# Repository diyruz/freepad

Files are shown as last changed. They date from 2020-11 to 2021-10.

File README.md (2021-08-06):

# Freepad

Freepad is an open-source Zigbee remote intended to be used to have a customizable keypad to control your smart home devices.  

## How to compile
Follow this article https://zigdevwiki.github.io/Begin/IAR_install/

## There are different hardware versions of the console.
More details on the links:
* [Freepad v1](https://github.com/diyruz/freepad/README_FREEPAD_v1.md)
* [Freepad v2](https://github.com/diyruz/freepad/README_FREEPAD_v2.md)
* [LeTV mod](https://github.com/diyruz/freepad/README_LETV.md)

## Features list:
1. Single/double/triple/quadruple/many_x/hold&release
2. Touchlink reset
3. ONOFF bind
4. Level control bind
5. Bindings configuration
6. Remote reset

## How to join:
1. Press and hold the *first* button for 3-10 seconds (depending on whether the device is connected to the network) until the LED on the device flashes.
2. Wait, if the connection is successful, the device will blink 5 times.
3. If the connection fails, the device will blink 3 times.

***Find button mapping at project page***

### Support
The keypad is supported in:
* zigbee2mqtt via int & ext converter
* ioBroker
* SLS Gateway

## Settings
In zigbee2mqtt you could change the setting at Exposes tab.
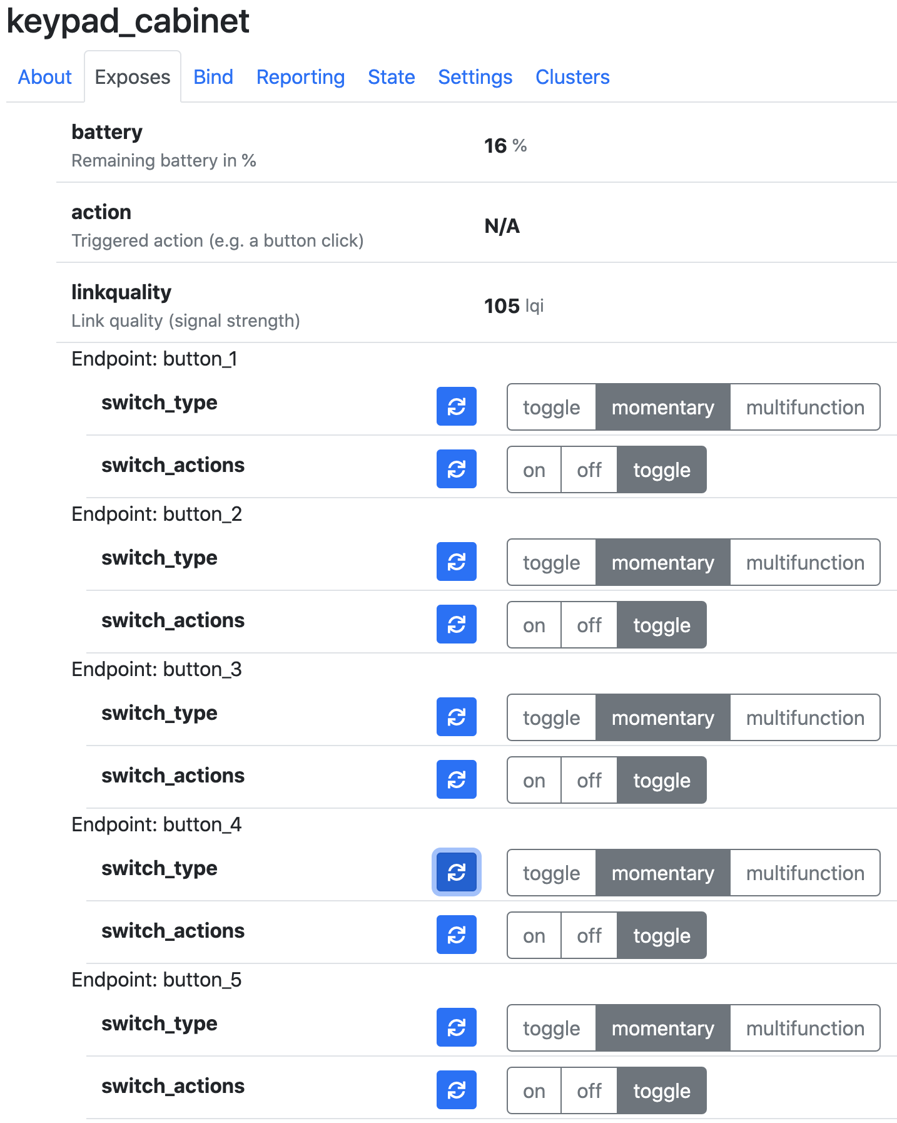
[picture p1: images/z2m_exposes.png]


### Work modes
By default remote works as a custom switch, with multiple clicks, but this behaviour has its drawback.
To detect multiple clicks, the remote sends commands with a 300ms delay.
You can change this behaviour by the cost of double/triple/etc clicks.

To do that you need to change

`ZCL_CLUSTER_ID_GEN_ON_OFF_SWITCH_CONFIG` cluster `ATTRID_ON_OFF_SWITCH_TYPE` attribute

Values are:

`ON_OFF_SWITCH_TYPE_MOMENTARY` (0) -> no delay, but no multiple clicks, only single

```bash
mosquitto_pub -t "zigbee2mqtt/FN/BUTTON_NUM/set/switch_type" -m '0'
```

`ON_OFF_SWITCH_TYPE_MULTIFUNCTION` (2) -> 300ms delay, full set of clicks

```bash
mosquitto_pub -t "zigbee2mqtt/FN/BUTTON_NUM/set/switch_type" -m '2'
```

### ONOFF cluster binding
By default command is TOGGLE, but you can change this behaviour.

Change `ZCL_CLUSTER_ID_GEN_ON_OFF_SWITCH_CONFIG` clusters attribute `ATTRID_ON_OFF_SWITCH_ACTIONS`

`ON_OFF_SWITCH_ACTIONS_ON`

```bash
mosquitto_pub -t "zigbee2mqtt/FN/BUTTON_NUM/set/switch_actions" -m '0'
```

`ON_OFF_SWITCH_ACTIONS_OFF`

```bash
mosquitto_pub -t "zigbee2mqtt/FN/BUTTON_NUM/set/switch_actions" -m '1'
```

`ON_OFF_SWITCH_ACTIONS_TOGGLE` (default value)

```bash
mosquitto_pub -t "zigbee2mqtt/FN/BUTTON_NUM/set/switch_actions" -m '2'
```

### Video
[@Vlad_Kolobov](http://t.me/@MoNo320) recorded a video showing the speed in two modes
video_speed_compare (https://www.youtube.com/watch?v=XvhNs9Tn12M)

### Acronyms in firmware file names

TL - touchlink

PM3 - Power Mode 3 (External Interrupts): 0.4 μA

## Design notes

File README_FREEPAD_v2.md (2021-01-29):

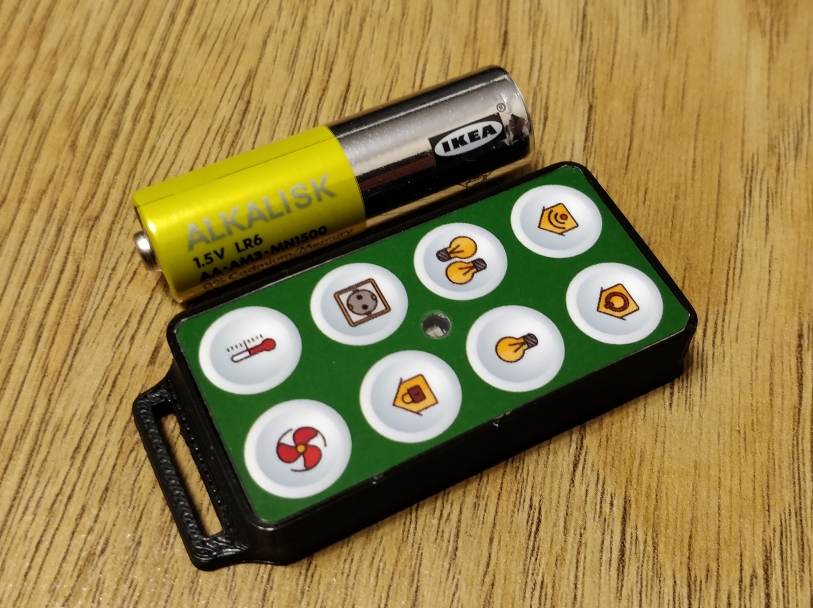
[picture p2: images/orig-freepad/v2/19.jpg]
  

The first version of the Zigbee remote control is good, but this option is not suitable when mobility is needed. For this reason, a second version appeared, in which Jager tried to make a more compact version.

Since 20 buttons are not always and not always needed, Jager had to come up with a board design that allows you to assemble 3 versions of remotes, for 20, 12, and 8 buttons. The following is a process with pictures and short explanations.

The circuit is almost identical to the first version
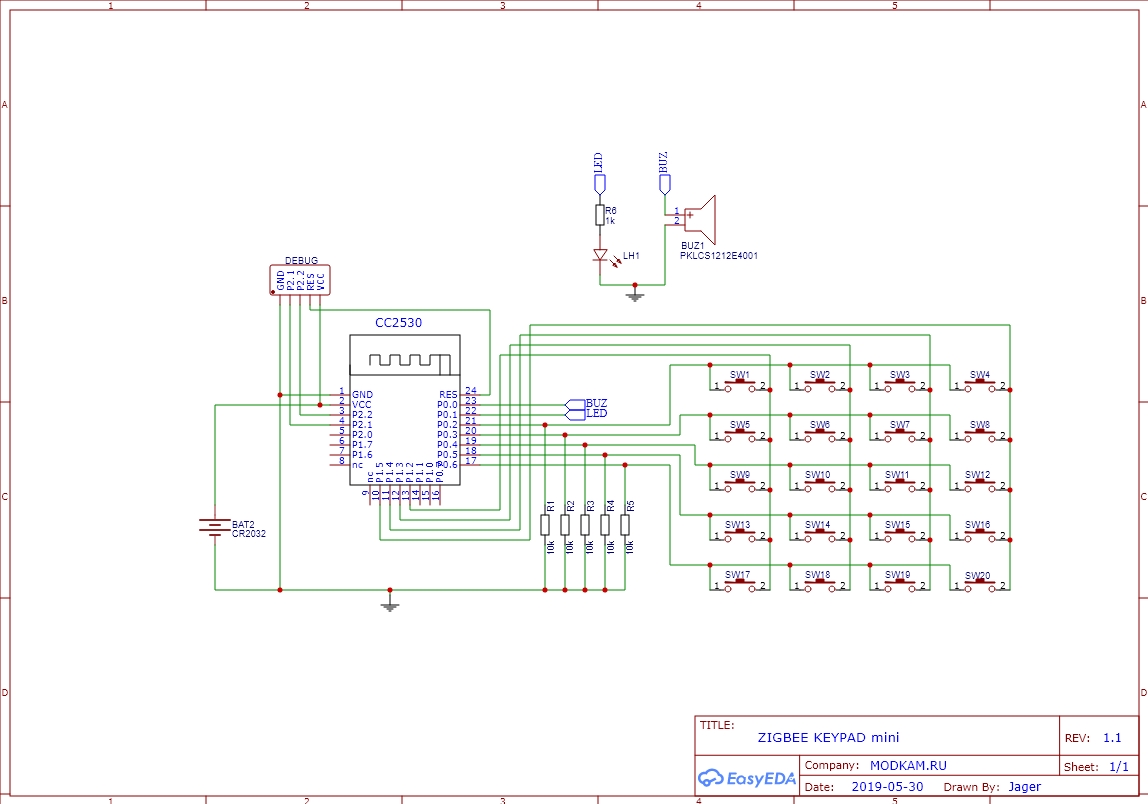
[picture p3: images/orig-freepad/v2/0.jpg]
  

using the Zigbee module from EBYTE E18-MS1-PCB
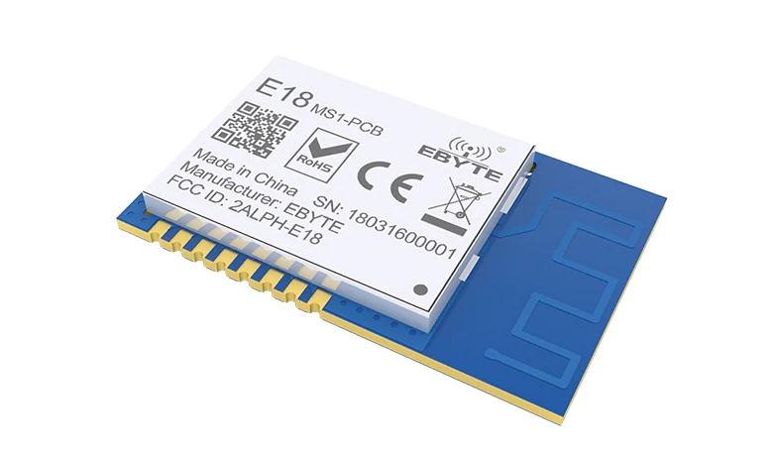
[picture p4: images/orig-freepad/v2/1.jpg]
  

compact buttons 3x4x2 mm
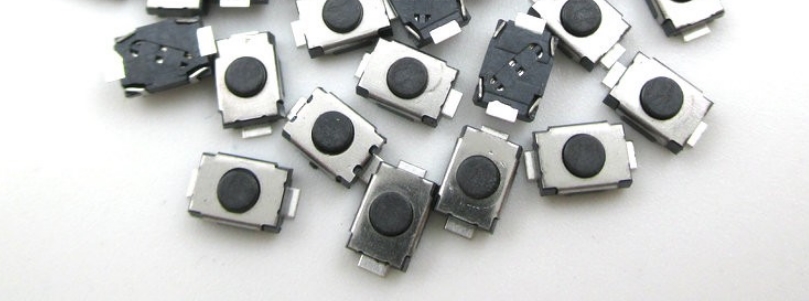
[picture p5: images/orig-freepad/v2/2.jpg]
  

The board is wired in DiTrace  
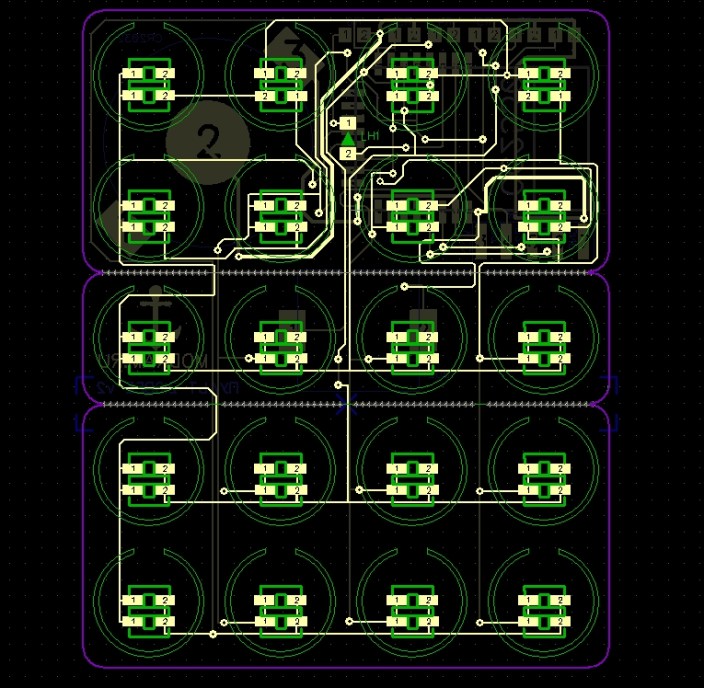
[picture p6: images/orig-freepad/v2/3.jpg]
  
Note that the contact pads for the buttons are not designed for 4 pin buttons, as it might seem, these are options for a different offset from the center, due to the design of the case.

Perforation is clearly visible on the renders, in these places unnecessary buttons are “broken off”. The very idea of separating the excess is certainly not new, but those restrictions are imposed on the flight of thought. manufacturer's conditions. Instead of cutouts, Jager had to make holes with a diameter of 0.3 mm.
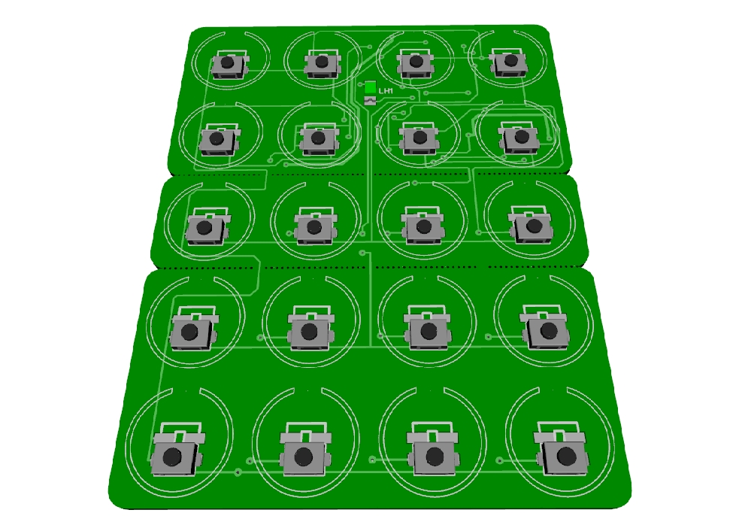
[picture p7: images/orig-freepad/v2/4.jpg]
  

Boards ordered in JLCPCB
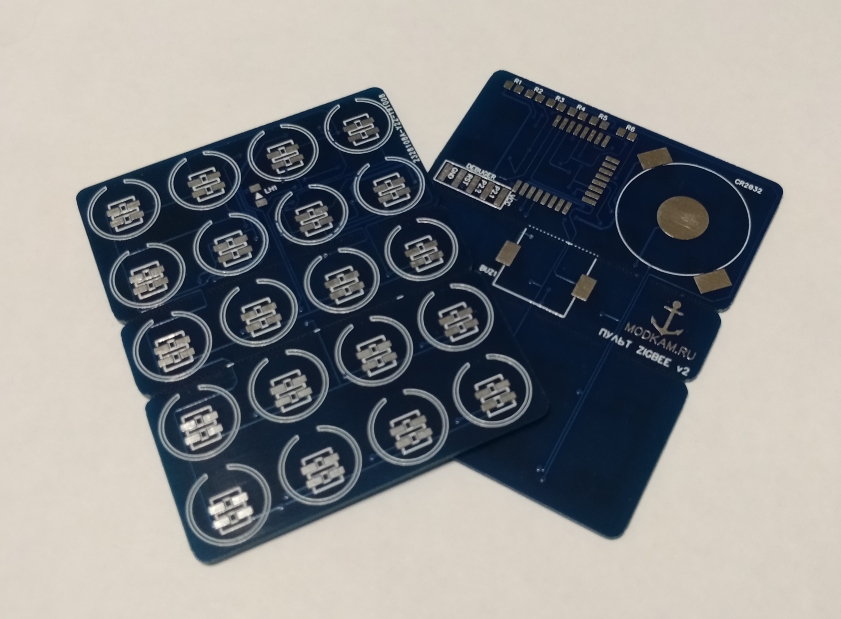
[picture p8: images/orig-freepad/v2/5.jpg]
  

Minimum soldering  
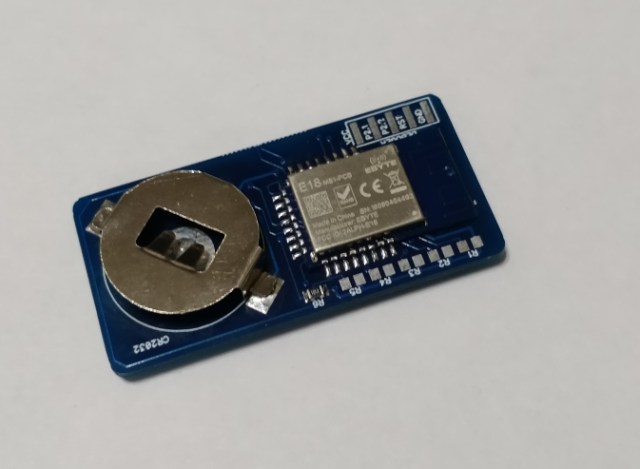
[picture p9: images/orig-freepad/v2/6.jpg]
  

Made a variant of the case for eight buttons in the form of a keychain. 
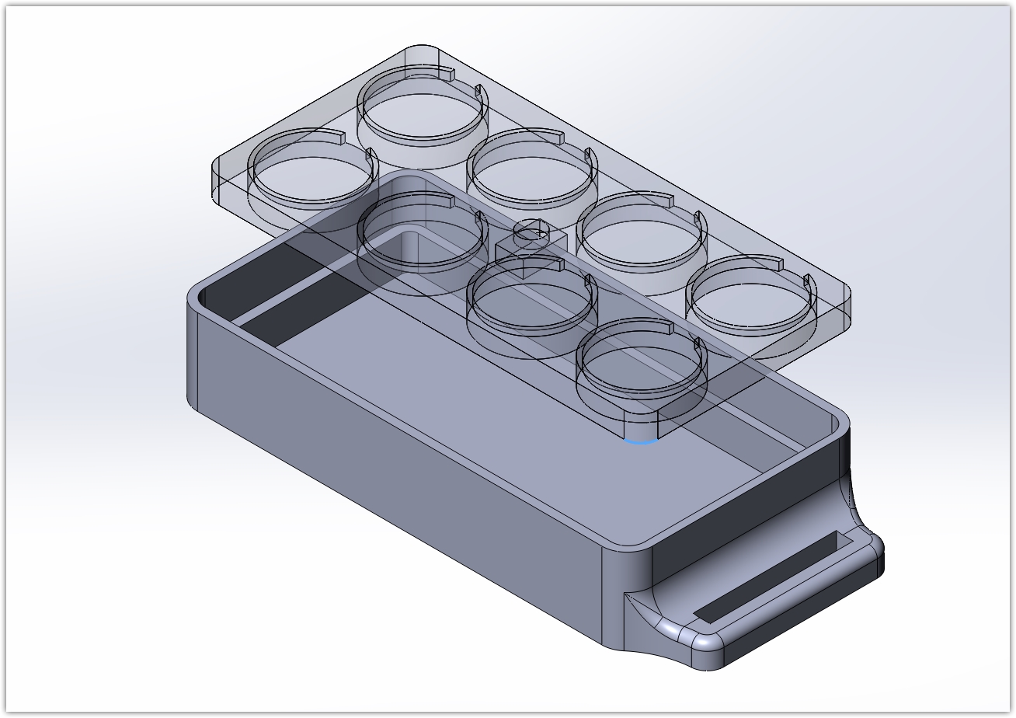
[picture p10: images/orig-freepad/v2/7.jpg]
  
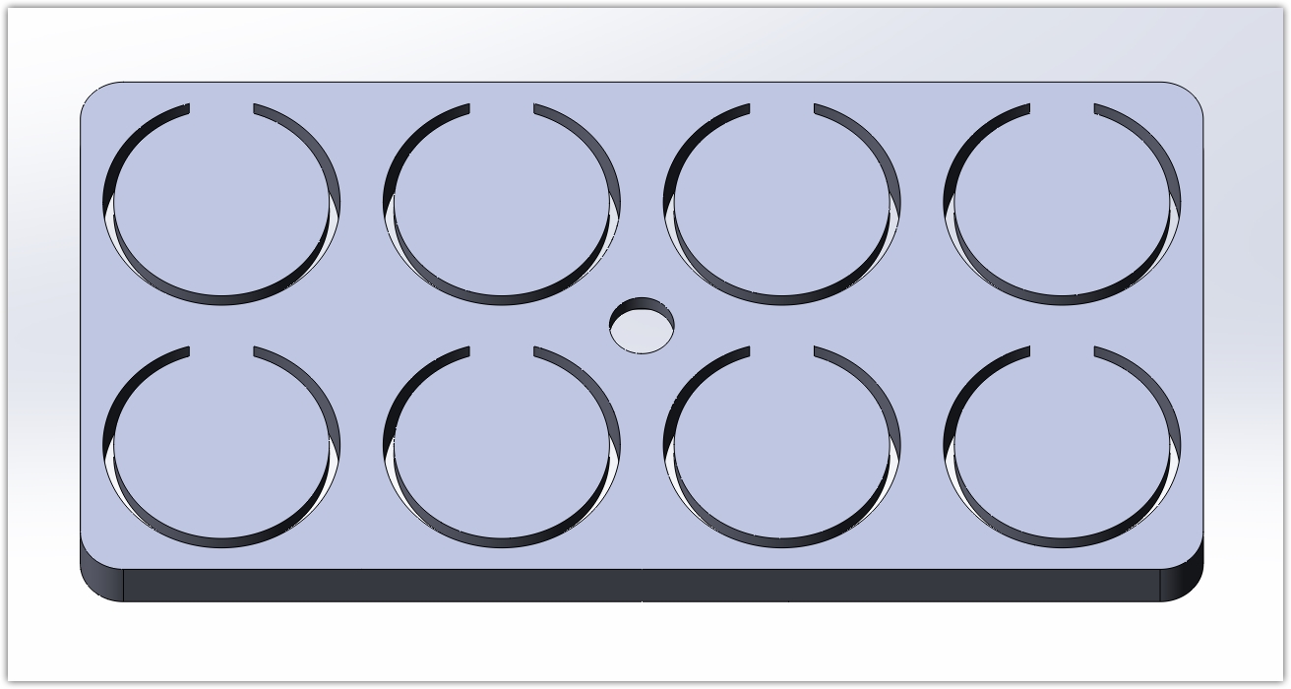
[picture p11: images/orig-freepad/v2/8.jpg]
  
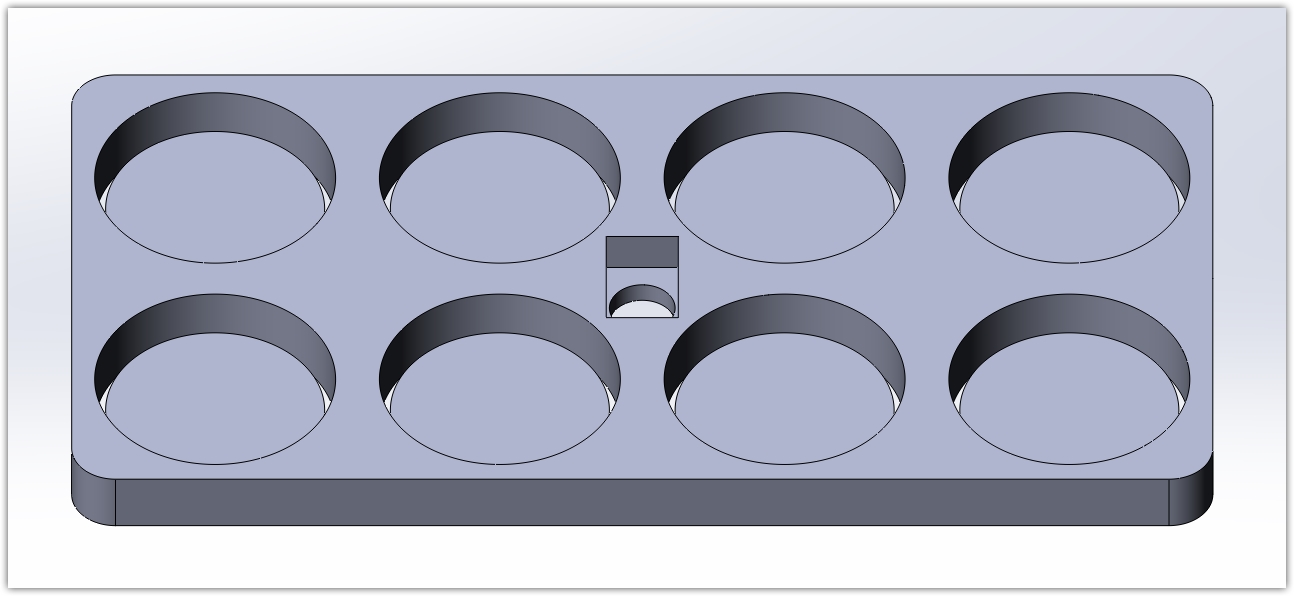
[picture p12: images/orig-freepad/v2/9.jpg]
  
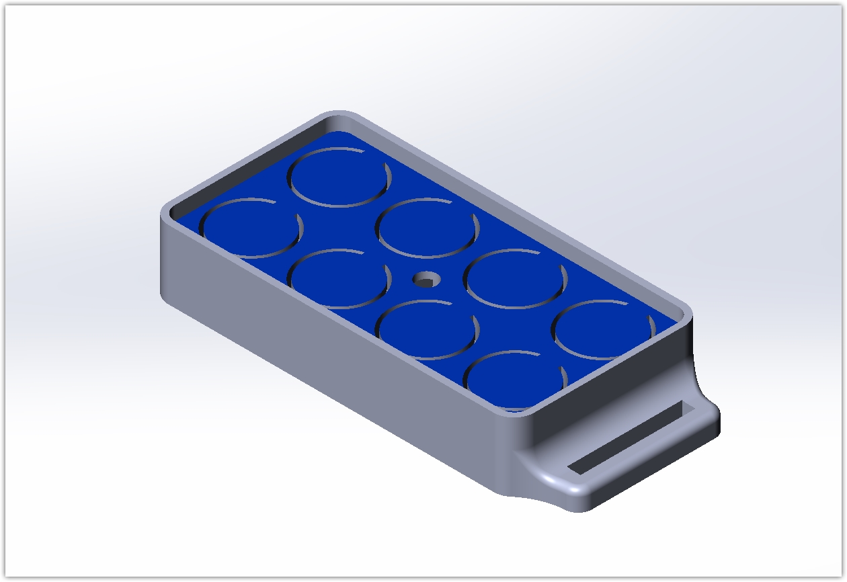
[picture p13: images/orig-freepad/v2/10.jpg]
  

The general idea is this, the insert on top of the board allows you to distribute the force over a larger area
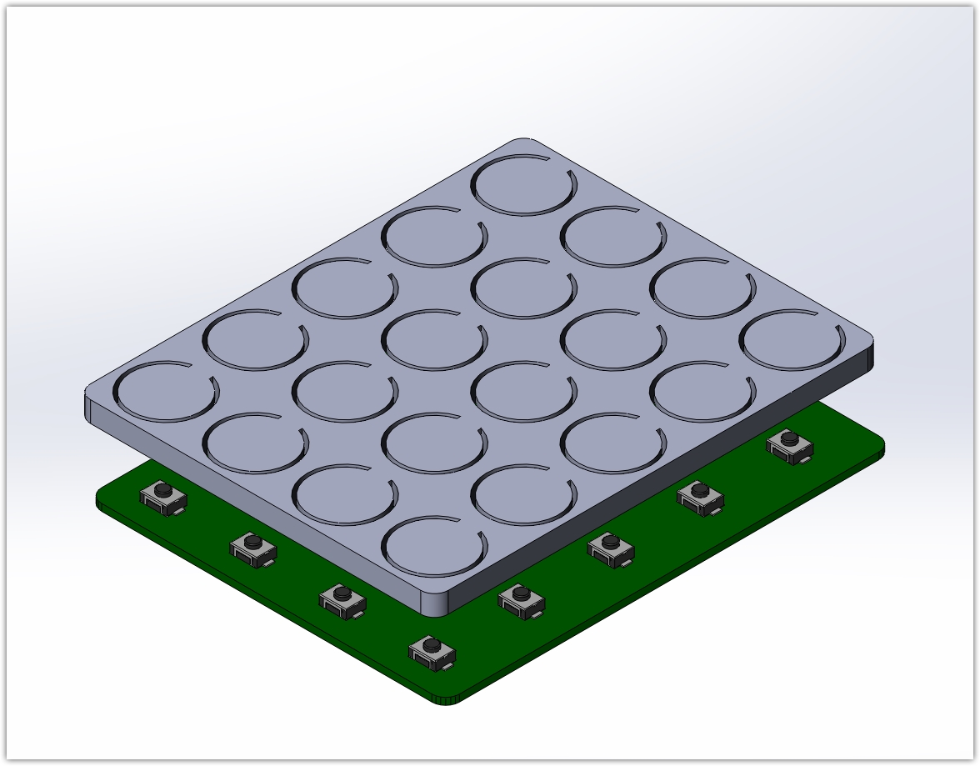
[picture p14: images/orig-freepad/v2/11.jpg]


Printed on 3d printer  
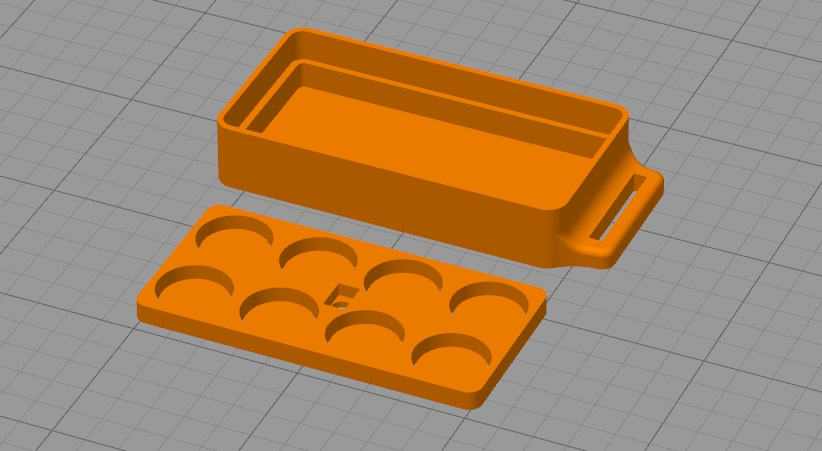
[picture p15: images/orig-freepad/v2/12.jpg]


First tried on  
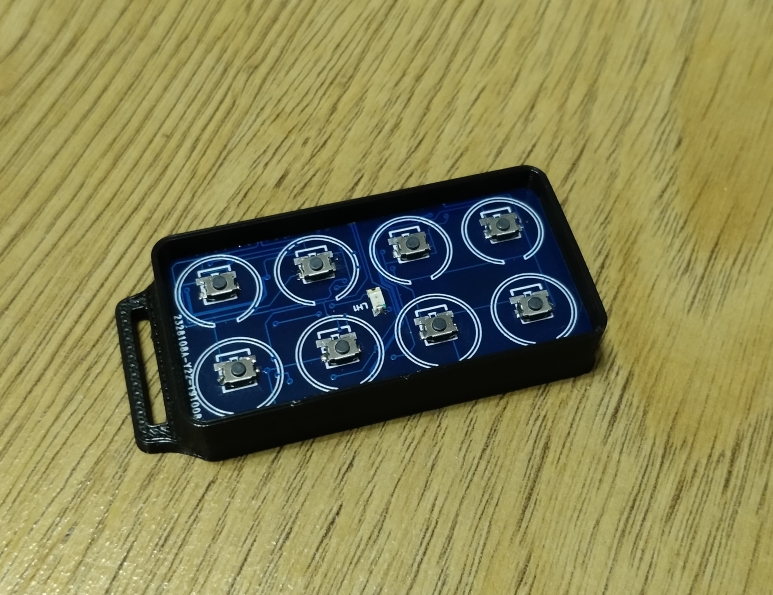
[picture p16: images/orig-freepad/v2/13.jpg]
  

The keyboard
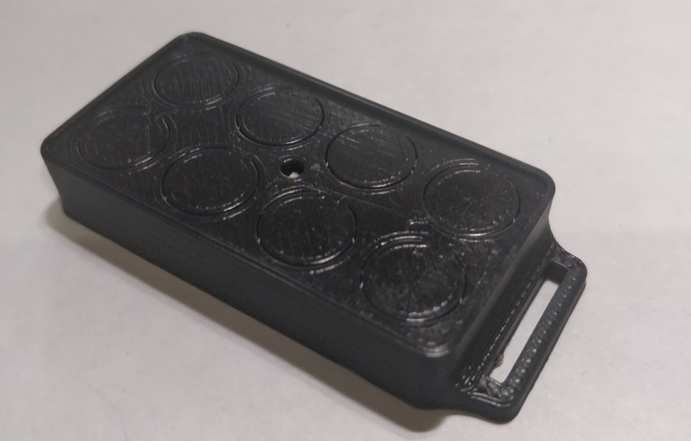
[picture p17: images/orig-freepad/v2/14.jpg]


Different colors  
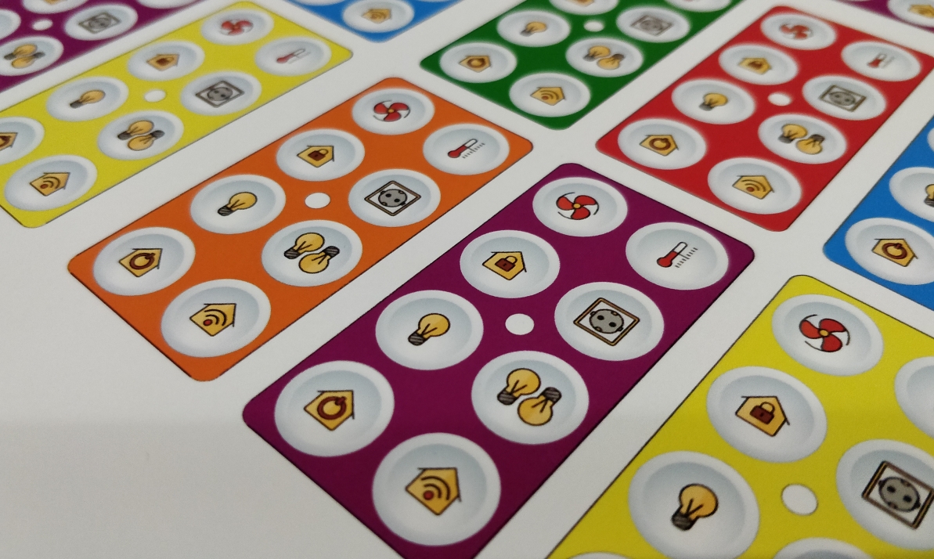
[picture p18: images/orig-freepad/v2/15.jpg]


Lamination will protect the paper keyboard

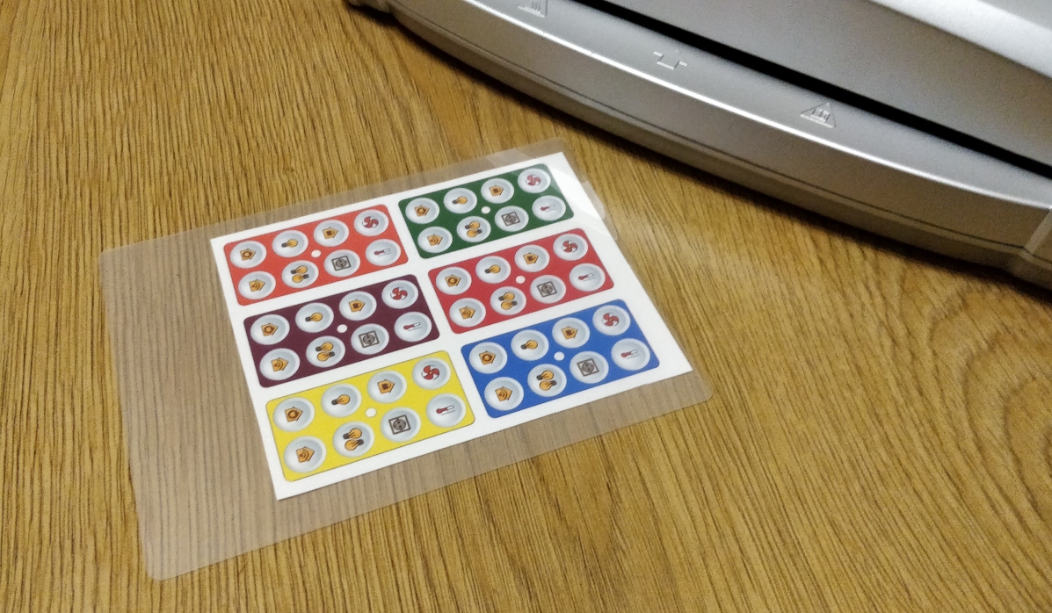
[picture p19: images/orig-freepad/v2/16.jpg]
  

Remains only to cut and try  
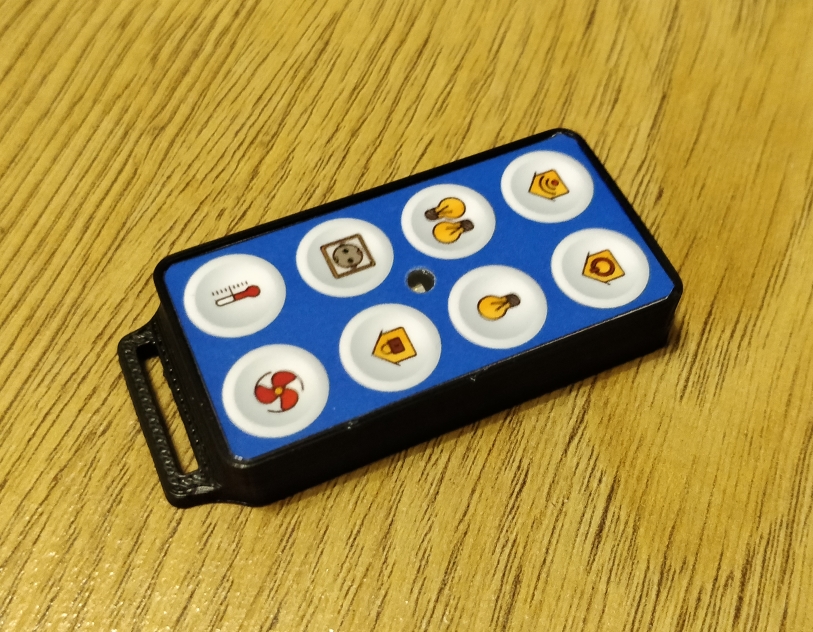
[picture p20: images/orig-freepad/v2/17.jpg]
  
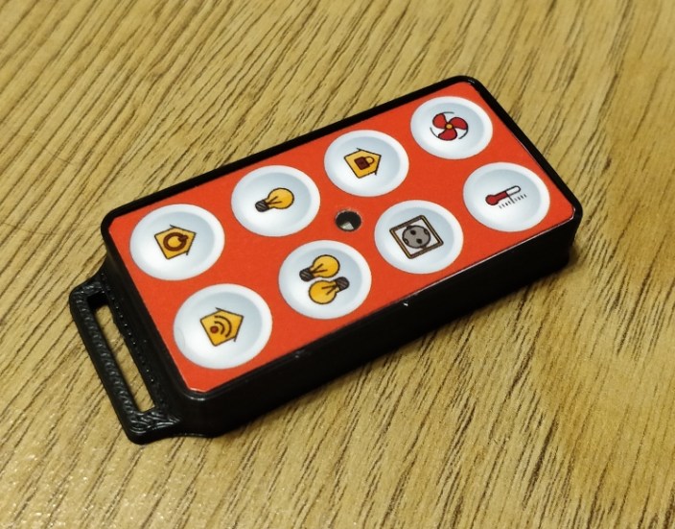
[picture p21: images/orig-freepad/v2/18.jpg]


In scale  
  
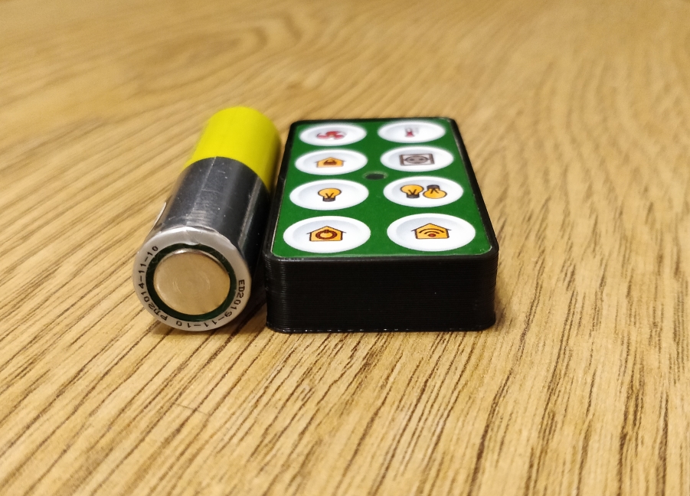
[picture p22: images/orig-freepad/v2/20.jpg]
  

Compared to first version  
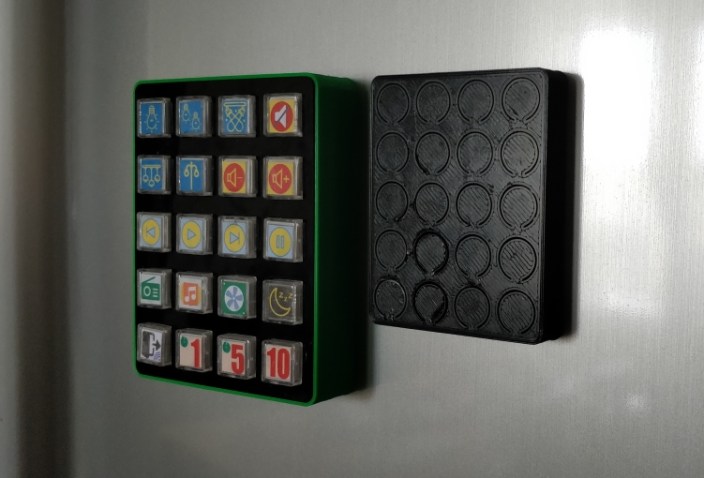
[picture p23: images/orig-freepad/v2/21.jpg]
  

From the software point of view, the consoles are identical.

@anonymass has written a open source firmware. The firmware has a lot of  options, binding, multi-click, etc. High stability and speed.

@nick7zmail repeated the construction, making the original keyboard
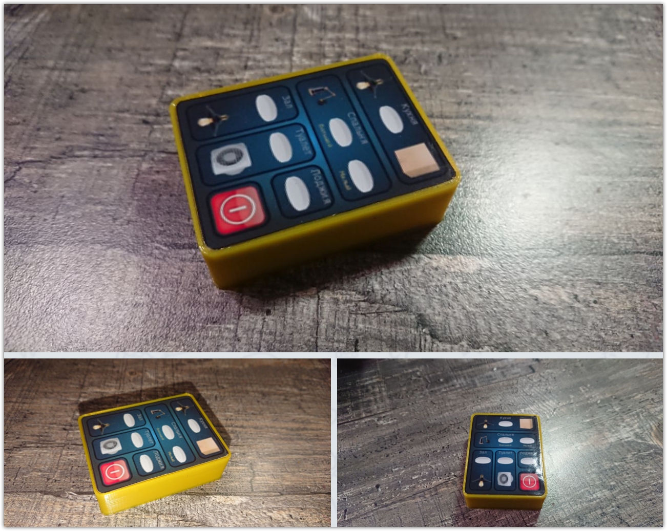
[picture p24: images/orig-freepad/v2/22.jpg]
  

but he did not stop there and made various housing options, for 8, 12, and 20 buttons.
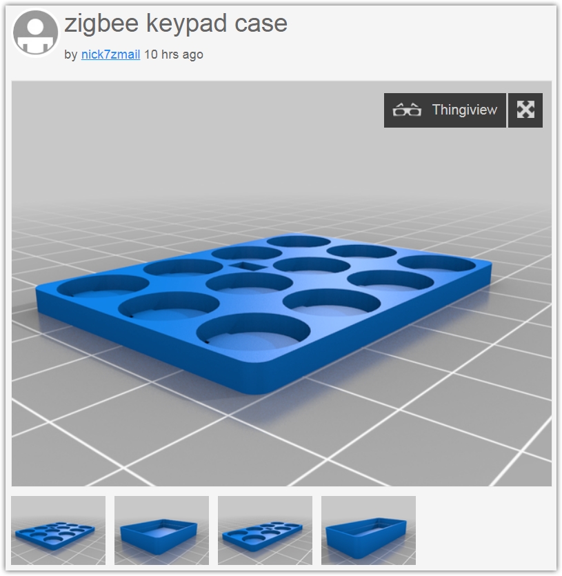
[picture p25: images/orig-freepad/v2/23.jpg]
  

@Madjestik58 designed and manufactured his version of the 4 button remote all necessary files for manufacturing are included.
  

Another version of the case for the keypad from obihoernchen
  

### What's button mapping?


### Files to reproduce
* [Gerbers and STL for 8 button](https://github.com/diyruz/freepad/hardware/v2) by [Jager](https://t.me/Jager_f)  
* [EasyEDA and STL for 4 button](https://github.com/diyruz/freepad/hardware/4_buttons) by [@Madjestik58](https://t.me/Madjestik58)  
* [Housing for 8, 12 and 20 buttons](https://www.thingiverse.com/thing:4161582) by [@nick7zmail](https://connect.smartliving.ru/profile/225)  
* [Housing for 20 buttons](https://www.thingiverse.com/thing:4668986) by [obihoernchen](https://www.thingiverse.com/obihoernchen)  
* [Firmware](https://github.com/diyruz/freepad/releases) by [@anonymass](https://t.me/anonymass)  
choose firmware hex file __without LeTV__ suffix

[Original post by Jager](https://modkam.ru/?p=1264)

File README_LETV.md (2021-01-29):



Some time ago, digging TaoBao, Jager has found an interesting miniature ZigBee remote control keypad with eight buttons.
As this device is powered by a CC2530 chip, an idea appeared in Jager's head to flash it with a great [freepad](https://github.com/diyruz/freepad/) firmware, which was used in Jager's previous remote controls.

UPD: This keypad has appeared on [AliExpress](https://aliexpress.ru/item/1005001962088229.html?&sku_id=12000018238549831)

Keypad has 8 buttons, two-colored led, and is powered by CR2032 lithium cell.




It is quite easy to disassemble this device. The case is held by plastic latches, and two screws hid beneath the white ring.



A totally disassembled keypad looks like this:





There are membrane buttons, held by a scotch duct-tape on the PCB.
The scotch-tape hides firmware flashing pads, so you need to remove it or cut a window to have access.



As you can see, contacts are located in a pretty chaotic order. I don't wish to solder wires and that's why I decided to make a flashing adapter.







The only thing you need to do is to upload the modified by [@xyzroe](https://t.me/xyzroe) version of freepad [firmware](https://github.com/diyruz/freepad/) with any
situated flashing [method](https://zigbee.wiki/books/%D0%BF%D1%80%D0%BE%D1%88%D0%B8%D0%B2%D0%BA%D0%B8/page/%D0%BF%D1%80%D0%BE%D1%88%D0%B8%D0%B2%D0%BA%D0%B0-cc2531cc2530).
Zigbee2mqtt converter file is included in the package archive.

Here is how the device attached to the [SLS Gateway](https://slsys.github.io/Gateway/README_rus.html) looks like:




### What's button mapping?


### Links
 - [DXF-file](https://github.com/diyruz/freepad/hardware/letv) by [Jager](https://t.me/Jager_f)  
   for DIY flashing adapter.

 - [Freepad firmware releases](https://github.com/diyruz/freepad/releases/latest)  
   choose firmware hex file with __LeTV__ suffix.  

 - [Flash instruction (in Russian)](https://zigbee.wiki/books/%D0%BF%D1%80%D0%BE%D1%88%D0%B8%D0%B2%D0%BA%D0%B8/page/%D0%BF%D1%80%D0%BE%D1%88%D0%B8%D0%B2%D0%BA%D0%B0-cc2531cc2530)  
   In Russian for now, but links and pictures are not less useful.

[Original post by Jager](https://modkam.ru/?p=1791)

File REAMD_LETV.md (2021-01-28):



Some time ago, digging TaoBao, I've found an interesting miniature ZigBee remote control keypad with eight buttons.
As this device is powered by a CC2530 chip, an idea appeared in my head to flash it with a great [freepad](https://github.com/diyruz/freepad/) firmware, which was used in my previous remote controls.

UPD: This keypad has appeared on [Aliexpress](https://aliexpress.ru/item/1005001962088229.html?&sku_id=12000018238549831)

Keypad has 8 buttons, two-colored led, and is powered by CR2032 lithium cell.




It is quite easy to disassemble this device. The case is held by plastic latches, and two screws hid beneath the white ring.



A totally disassembled keypad looks like this:





There are membrane buttons, held by a scotch duct-tape on the PCB.
The scotch-tape hides firmware flashing pads, so you need to remove it or cut a window to have access.



As you can see, contacts are located in a pretty chaotic order. I don't wish to solder wires and that's why I decided to make a flashing adapter.







The only thing you need to do is to upload the modified by [@xyzroe](https://t.me/xyzroe) version of freepad [firmware](https://github.com/diyruz/freepad/) with any 
situated flashing [method](https://zigbee.wiki/books/%D0%BF%D1%80%D0%BE%D1%88%D0%B8%D0%B2%D0%BA%D0%B8/page/%D0%BF%D1%80%D0%BE%D1%88%D0%B8%D0%B2%D0%BA%D0%B0-cc2531cc2530).
Zigbee2mqtt converter file is included in the package archive.

Here is how the device attached to the [SLS Gateway](https://slsys.github.io/Gateway/README_rus.html) looks like:




[Original post by Jager](https://modkam.ru/?p=1791)

### Links
 - [DXF-file](https://www.dropbox.com/s/y3p7kqxyiqmid25/LeTV_pogopin.dxf?dl=0)  
   for DIY flashing adapter.

 - [Freepad firmware releases](https://github.com/diyruz/freepad/releases/latest)  
   choose firmware hex file with __LeTV__ suffix.  

 - [Flash instruction (in Russian)](https://zigbee.wiki/books/%D0%BF%D1%80%D0%BE%D1%88%D0%B8%D0%B2%D0%BA%D0%B8/page/%D0%BF%D1%80%D0%BE%D1%88%D0%B8%D0%B2%D0%BA%D0%B0-cc2531cc2530)  
   In Russian for now, but links and pictures are not less useful.

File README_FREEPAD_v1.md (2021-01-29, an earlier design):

  

This is a kind of universal remote control, which displays the most frequently used functions in a particular room. This can be lighting control, multimedia equipment, various UD scenarios, etc.

This remote control will live in the kitchen, the icons show that it will be possible to control the light, hood, music, set the timer.

The device is based on a module from EBYTE E18-MS1-PCB or E18-MS1PA1-PCB if an increased communication range is required.
  
The advantages of this module are cheapness and ultra-low consumption, 0.4 μA in deep sleep mode.

The scheme uses a matrix of 20 buttons. The remote control is powered by one CR2032 element if a 2.5mW module is used, and from two elements via an LDO when using a 100mW module. There is also a LED and a buzzer on the diagram to indicate both the actual operation of the buttons and the display of service modes.  
  

The dimensions of the device are determined by buttons 12x12x7.3 mm with transparent covers, I must say on AliExpress, their choice is very limited and this is practically the only option. There is a version with contacts for surface mounting. , but you can also use such as in the picture, it is enough to "bite off" the legs flush with the body.  
  

The board was spread in DipTrace


Virtual result
  
  
Satisfied with the result, Jager place an order for the boards.

While the boards are being manufactured, Jager engaged in the case,
  
  

Then print on a 3D printer. For fastening to a metal surface, magnets 9 x 1.5 mm are provided, with an effort they snap into place. Fastening the board with M3x5 screws.
  

The upper part can also be printed, but it is much more aesthetically pleasing to cut out with a laser from plexiglass. Light transmittance 2%, enough to see the glow of the LED and hide the insides, 3mm thick.  Held in place by friction.  
  

Printed pictograms for buttons  
  

The boards are ready  
  

a little soldering  
  

and can be assembled for size estimation,
  
  

in comparison with the IKEA TRÅDFRI remote control
  

element AA
  

Variant of fastening to a metal surface  


The original firmware was written by Vladislav @DJONvl, support in the ioBroker driver was provided by Kirov Ilya @goofyk, for which special thanks to them.  
  

Consumption corresponds to the one declared by the manufacturer, which will allow the remote control to work from one CR2032 element from 1 to 2 years.  
  

The firmware implements both light and sound indications of pressing. There is a network presence control (if the device is out of the network, pressing the buttons is not confirmed by light and sound). Work on the functionality of the firmware continues, possibly binding, and other options will appear.

@anonymass has written a new open-source firmware. The firmware added a lot of new options, binding, multi-click, etc. Significantly improved stability and speed.

@Madjestik58 made his version of the case using other buttons, 12x12 5mm high. It turned out great!  

  

### What's button mapping?
 

### Files to reproduce
* [Gerbers, STL, DXF](https://github.com/diyruz/freepad/hardware/v2) by [Jager](https://t.me/Jager_f)  

* [Another housing](https://www.thingiverse.com/thing:4256330) by [@Madjestik58](https://t.me/Madjestik58)  

* [NEW firmware](https://github.com/diyruz/freepad/releases) by [@anonymass](https://t.me/anonymass)  
choose firmware hex file  __without LeTV__ suffix  

* [OLD original firmware hex](https://github.com/diyruz/freepad/hardware/v1/maxPW_key17setup_DIYRuZ_KEYPAD20.hex) by @DJONvl

[Original post by Jager](https://modkam.ru/?p=1114)

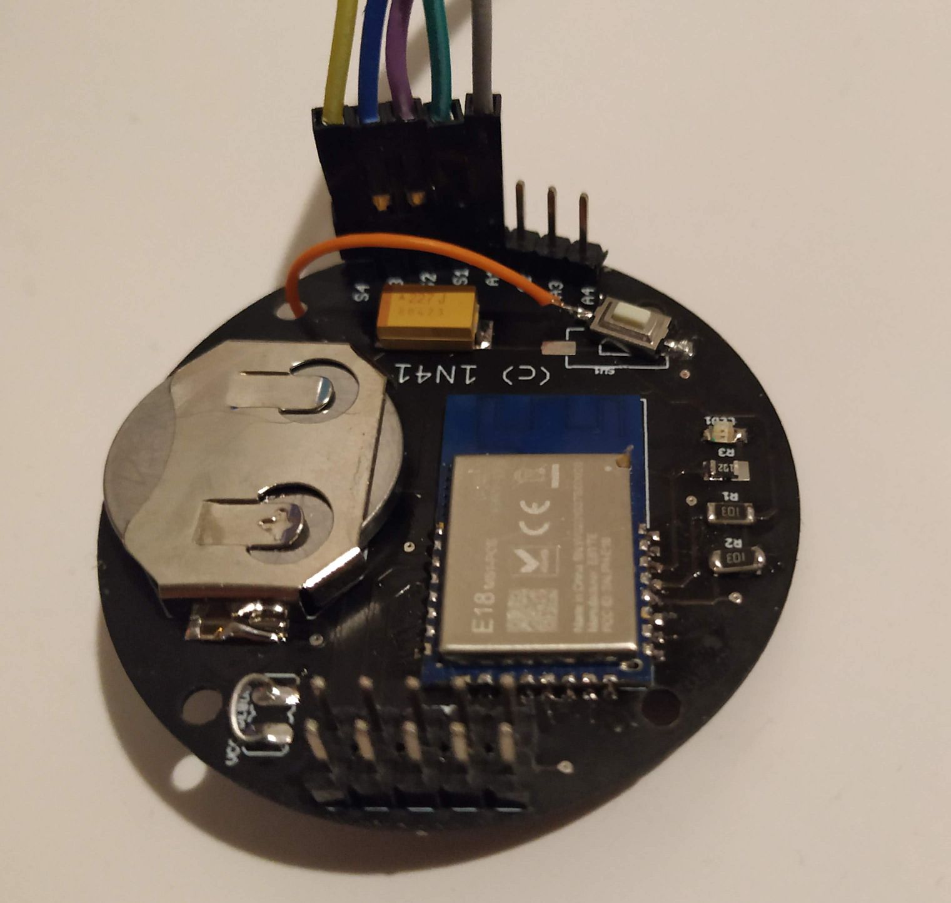
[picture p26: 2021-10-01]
hardware/round-switch.jpeg

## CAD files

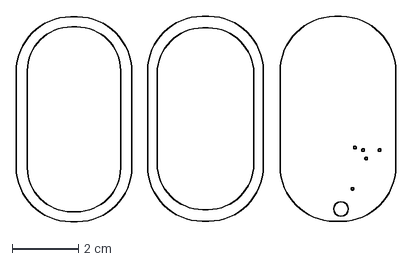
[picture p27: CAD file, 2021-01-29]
hardware/letv/LeTV_pogopin.dxf
11.5 x 6.22 cm

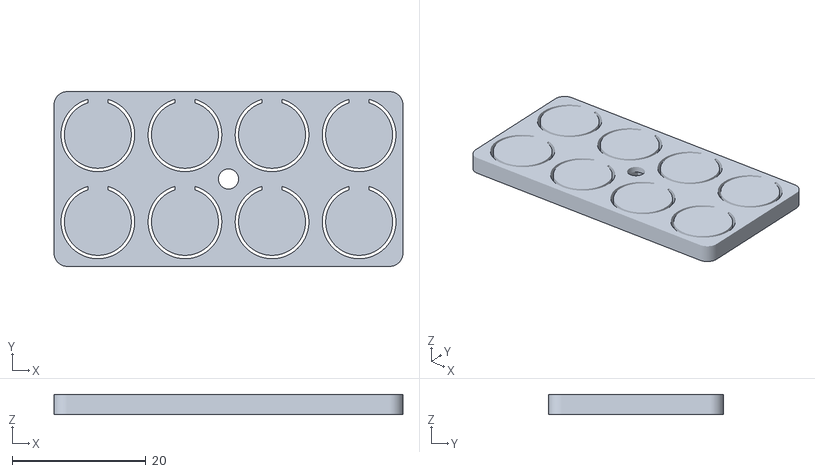
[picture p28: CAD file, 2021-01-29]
hardware/v2/case_v2_8key_top.STL
52.1 x 26.1 x 3.00

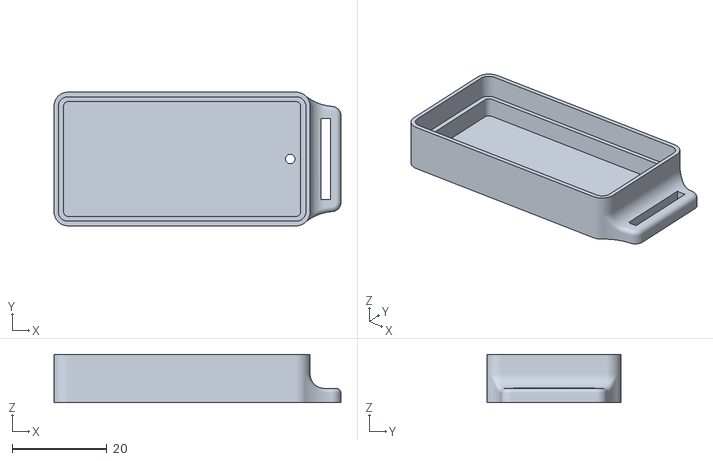
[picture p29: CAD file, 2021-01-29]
hardware/v2/case_v2_8key_bottom.STL
60.5 x 28.2 x 10.2

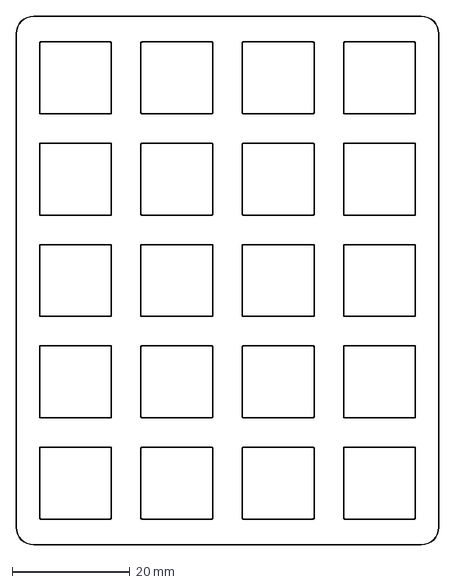
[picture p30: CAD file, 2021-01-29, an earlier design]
hardware/v1/top_glass_v1.DXF
71.8 x 89.8 mm

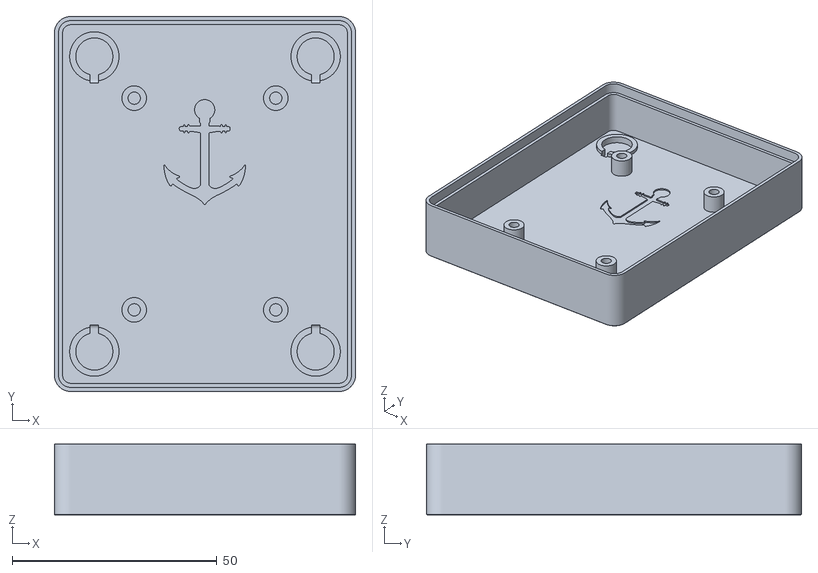
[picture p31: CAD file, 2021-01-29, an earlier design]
hardware/v1/case_v1.STL
73.5 x 91.5 x 17.3

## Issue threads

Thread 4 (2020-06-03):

20 single click version

hqas, 2020-06-03:
As I am not that familiar with coding, would it be possible to upload the only single click version of the 20 button keypad ?

nurikk, 2020-06-03:
Kindly check release download version, already has 1/2/3/8/12/20 types

hqas, 2020-06-03:
Yes i saw them and I am using the 20 type without a problem. But as I dont need multiple clicks I prefer the "ON_OFF_SWITCH_TYPE_MOMENTARY (0) -> no delay, but no multiple clicks, only single" version

nurikk, 2020-06-03:
then use `mosquitto_pub` to configure your device, readme has examples

hqas, 2020-06-04:
Ah now I understood how to configure. Thx

Closed 2020-06-04.

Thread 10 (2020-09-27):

transmission of data on real voltage on the battery.

JerryLutor, 2020-09-27:
the system always gives a value of 2900, is it possible to get real data on the voltage on the battery?

nurikk, 2020-09-28:
It's already sending real voltage, the reason why it's always 2900(2.9 volts or 2900 millivolts) because the remote doesn't drain much current from the battery and it battery charge is the same

Closed 2020-11-11.

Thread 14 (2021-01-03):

PM3 and no PM3 the difference

qlwz, 2021-01-03:
NO PM3 is PM1 OR PM2？

PM3 is PM2 OR PM3？

nurikk, 2021-01-04:
No PM is PM2

qlwz, 2021-01-04:
PM3 need rejoin ?
the first key press is slow

==============================log=======================

debug 2021-01-04 01:18:00: Device '0x00124b000adb81f7' announced itself
info  2021-01-04 01:18:00: MQTT publish: topic 'z2m_2_b/bridge/event', payload '{"data":{"friendly_name":"0x00124b000adb81f7","ieee_address":"0x00124b000adb81f7"},"type":"device_announce"}'
info  2021-01-04 01:18:00: MQTT publish: topic 'z2m_2_b/bridge/log', payload '{"message":"announce","meta":{"friendly_name":"0x00124b000adb81f7"},"type":"device_announced"}'
debug 2021-01-04 01:18:02: Received Zigbee message from '0x00124b000adb81f7', type 'attributeReport', cluster 'genMultistateInput', data '{"presentValue":1}' from endpoint 7 with groupID 0
info  2021-01-04 01:18:02: MQTT publish: topic 'z2m_2_b/0x00124b000adb81f7', payload '{"action":"button_7_single","battery":15,"elapsed":1014428,"linkquality":0,"voltage":2700}'

sharathbk1912, 2022-03-21:
Hi @qlwz , with pm3 i am seeing after a while it repairs and it misses the keypad event as such

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

were you able to resolve this ? also which coordinator firmware are you using ?

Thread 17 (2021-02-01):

z2m and LeTV

AlexeyHimki, 2021-02-01:
DIYRuZ_FreePad_LeTV.hex Release 2.0.7
zigbee2mqtt-1.17.0

The problem:

Zigbee2MQTT:error 2021-02-01 11:04:26: Failed to interview '0x00124b000adb260f', device has not successfully been paired

AlexeyHimki, 2021-02-01:
After update to 1.17.1:

Zigbee2MQTT:error 2021-02-01 23:31:55: Failed to configure '0x00124b000adb260f', attempt 1 (Error: Bind 0x00124b000adb260f/1 genPowerCfg from '0x00124b0018e2720a/1' failed (AREQ - ZDO - bindRsp after 10000ms)
    at Timeout._onTimeout (/zigbee2mqtt-1.17.1/node_modules/zigbee-herdsman/dist/utils/waitress.js:46:35)
    at listOnTimeout (internal/timers.js:554:17)
    at processTimers (internal/timers.js:497:7))

Ich-Eben, 2021-02-05:
I had a similar issue. Desoldering the LED worked for me. It seems that the LED draws to much current sometimes.

spasvisual, 2021-04-15:
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

Did you fix the problem?

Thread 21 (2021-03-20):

Make freepad as router?

borodamd, 2021-03-20:
Good day. I am planning to make inwall stationary freepad from modkam plans by Jager with persistent or time-changing backlights. Is any possibility to program it as zigbee router? Also, if it possible, how it will work in z2m and sls?
Thanks.

Английский у меня корявый, так что попробую продублировать по русски:
Доброго времени суток.
Есть планы сделать 20-кнопочный пульт в корпусе для подрозетника. С аппаратной частью проблем не вижу, а вот с программной, хотелось бы уточнить. Есть ли какая-либо возможность использовать этот девайс как роутер зигби, так как питание у него будет стационарное, а также возможность сделать настраиваемую подсветку на какой-либо GPIO. Насколько я понимаю, этот проект максимально заточен под энергоэффективность, но также хотелось бы узнать возможность использовать cc2538-cc2592 для лучшего сигнала.

И, насколько всё это, после переделок, сможет интегрироваться в z2m и sls. Залетит под уже готовые девайсы или придётся проталкивать их добавление?

Заранее спасибо за ответы.

nurikk, 2021-03-26:
Hello, I don’t have plans for adding a router feature. But if you dare enough to implement, go ahead! PR are always welcome. You can have a look on other diyruz projects which support end device and router builds (airsense, geiger)

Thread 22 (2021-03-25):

It's not a bug, it's a feature

1N4148, 2021-03-25:
I've made a small PCB that fits under a legacy wall switch into the wall box. If it's interesting I'll share the gerber files for the PCB

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

nurikk, 2021-03-26:
Hi! PR are always welcome! You can upload files into hardware directory

https://github.com/diyruz/freepad/tree/master/hardware

jmvaz, 2021-09-30:
Nice!!! Can you share the PCB? Whats the purpose of the switch on board? Is the pairing switch?? It would be nice to be able to pair the device without disassemble the wall plate!

1N4148, 2021-09-30:
These are my Eagle 7.5.0 Files. Have fun :)

[E18-MS1.zip](https://github.com/diyruz/freepad/files/7261823/E18-MS1.zip)

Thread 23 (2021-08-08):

how to flash?

boelle, 2021-08-08:
is https://zigdevwiki.github.io/Begin/IAR_install/ stille the guide on how to compile?

i want to make 5 button and 8 button remotes

how do i change settings before i compile the firmware? any english guides?

nurikk, 2021-08-09:
You don’t need a custom firmware for your case, just maintain current matrix schematic and do nothing else

boelle, 2021-08-09:
oki,

does it only work with zigbee2mqtt? i use deconz/phoscon

nurikk, 2021-08-09:
Afaik it’s supported by dezonz

boelle, 2021-08-10:
i put this in: https://github.com/blakadder/zigbee/pull/371

just so it can get an "official" approval mark

have you tested this yourself?

nurikk, 2021-08-10:
Oh no, I've mistaken freepad repo with flower repo. Freepad isn't supported buy deconz

boelle, 2021-08-10:
that is a shame, would have been perfect for my project

an 8 button version of this

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

AnthonMS, 2021-10-01:
A damn shame it's not supported in DeConz! As a fellow Dane, I would have loved an open source project like that!

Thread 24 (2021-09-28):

LeTV delay after pressing button.

tarasifua, 2021-09-28:
Hi! I had flashed Letv remote to this firmware. It works, but there is long delay (4-5 sec) between pressing button and sending command. Also tried to flash "DIYRuZ_FreePad_LeTV_PM3.hex" and "DIYRuZ_FreePad_LeTV_TL_PM3.hex" files, nothing changes. Remote connected via Zigbee v4 stick and z2m Home Assistant addon.
Also tried to play with "switch_type" options in z2m, but nothing help.
What I'm doing wrong?

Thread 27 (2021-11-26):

Flashing without CC Debugger?

phoenix1589, 2021-11-26:
I'm trying to work our what I need to get in order to be able to build and flash my own. With the provided binary, this should be easy with a CC Debugger; however I don't have one.

Can anyone advise how I can flash without the CC Debugger? or confirm if
https://www.zigbee2mqtt.io/guide/adapters/flashing/alternative_flashing_methods.html, as alternative method to flash a CC2531 (E18-MS1-PCB is based on CC2530) with just a Raspberry Pi and some dupont cables would work, using P2.1 as DD and P2.2 ad DC?

phoenix1589, 2022-02-13:
This worked

Closed 2022-02-13.

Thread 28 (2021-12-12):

Battery drain - LeTV

rafal83, 2021-12-12:
Hi,

I've flashed LeTV with "DIYRuZ_FreePad_LeTV_PM3.hex", device is used with direct binding to bulb, 5-10 switchs per day, no more 2 weeks with new battery :/

Any idea ?

rafal83, 2021-12-22:
Every 10-12s, wake up, eat 2mA  and sleep, in sleep mode 0.001mA

Consider, only wakeup, 2mA during 1ms,
in 1 hour there is 6*60 => 360 wake up => total consumtion => 0.72mA
in 1 day => 0.72 * 24 => 17.28 mA,

CR2032 has 230mA... 13 days of life

Why there is wake up every 10s ?

dxaudio, 2022-01-06:
I have noticed same behaviour. Cant use it as remote at all. Is it possible to change wake up time from 10s to 1h for instance?

mortenmoulder, 2022-01-11:
I can confirm the same thing, however, it seems like every 15 seconds it wakes up, then 10 seconds later it also wakes up, then wakes up 5 seconds later and repeats.

15 seconds wake up: ~300 milliseconds and uses ~2.8 mA
10 seconds wake up: ~40 milliseconds and uses 500 µA

Average power consumption: 150 µA

However, it only does this for 3 minutes, then it goes back to using ~85 µA on average.

Here is what 8 minutes look like including providing power at 00:00:

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

Here is what 4 minutes look like **AFTER** 3 minutes:

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

Here is what 1 minute and 15 seconds look like in the **FIRST** 3 minutes:

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

mortenmoulder, 2022-01-17:
I grabbed a brand new chip and even with a MCP1700 LDO, I got it down to ~4.7 µA after the first 3 minutes. No clue why a new chip worked out - maybe the old was faulty?

It still wakes up every 10-15 seconds for the first 3 minutes, but an average power consumption of 4.7 µA is not bad at all.

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

cryoutsolutions, 2022-01-26:
same problem, after two weeks even if I don't use the remote at all, the battery is drained. I use the pm3 version.

maarten682, 2022-09-01:
Any news on this? 2 weeks battery life kinda sucks....

cxw0102, 2022-11-10:
used pm3  ,

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
With ubiqua packet capture, it can be seen that the device will always send Data Request without entering PM3 mode.

countrysideboy, 2022-11-10:
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

The old version of hardware maybe need extra registers operation to turn the chip into deep sleeping mode.

Flavien, 2023-03-09:
@mortenmoulder So you got a new identical E18-MS1-PCB and its average consumption was lower than the first one you bought?

How is the battery life with the chip that draws 4.7 µA average?

mortenmoulder, 2023-03-09:
@Flavien I actually just installed FreePad PM3 on a brand new chip for a new project. No LDO or 18650 battery, but a CR2032 instead.

With power consumption of 4.7 µA average, you're looking at years of power with a 18650 battery.

Flavien, 2023-03-09:
The LDO was necessary because the 18650 battery is 3.7 V, is that right?

Do you think the problem was the problem caused by the use of a 18650 battery with LDO, or just that the first chip was defective? Or maybe there was a problem with the assembly of your first board?

mortenmoulder, 2023-03-09:
@Flavien The LDO was necessary because of the 18650 battery's high voltage, yeah. About 4.2 when fully charged.

I've had good and bad experiences with these EByte chips. I spoke with some very clever people, including the manufacturer, and it seems like the problem could be related to left-over flux residue, that needs to be cleaned on the outside with isopropyl alcohol or similar, but ultrasound (or something) on the inside of the shield. But, a low quality LDO could definitely also be the cause of this. If you heat it up ever so slightly too much, it could make it less efficient.

I've yet to test the actual power consumption of this new assembly, but I do know for a fact, that getting a PCB manufactured and you soldering the parts on, makes the power consumption go down, compared to leaving everything on a breadboard with jumper wires. I've tested that a bunch of times with these chips thus far.

Flavien, 2023-03-10:
@mortenmoulder Ok, that's interesting. The author of [this video](https://www.youtube.com/watch?v=w-uWYaFztoQ) got the PCB manufactured and soldered the parts, and didn't use a LDO, and he still reported in the comments that the best he got was 3 months of battery life...

It would be good to understand what is causing this. It looks like some people are affected and some are not.

alex2beard, 2023-08-30:
Очень быстрый разряд батареи ни удалось победить ? Два года проблеме )) Ни у кого не завалялось схемы выводов СС на кнопки ? Или конфига для PTVO ?

lych, 2023-09-15:
The same problem. I have two Freepads v1. Battery life is about 2-3 weeks on both.

danielducu, 2024-02-22:
2024 , anyone found solution to the battery problem on this ? Not getting more then 1 month of battery.

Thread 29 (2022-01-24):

Stability in Zigbee2MQTT

leoujz, 2022-01-24:
Does anyone meet the stability problem in Zigbee2MQTT? I flash the firmware to CC2530(E18-MS1-PA1), and it seems that very unstable.

(1) I use coordinator cc2652p, and very close to the 20 keys freepad v1, pcb antenna and ipex antenna all tried.
(2) it's hardly to be configured and interviewed, and only success for a few times in dozens of tries.
(3) after interviewed, press the button and no signal received by zigbee2mqtt
(4) in device exposes page, click multifunction for each key, somtimes success sometimes fail
(5) in devices binding/reporting setting page, sometimes set it successfully, and the button starts to work, report single/double/triple, and etc.
(6) but suddenly no signal received anymore, sometime power off will make it work again, but more times need to reset and pair the device again

Does anyone meet the same situation?  Is it possible that CC2530 is not powerful enough to run z-stack 3.0?

johanvh83, 2022-03-03:
Hi, I just flashed the E18-MS1-PA1 and use the same coordinator CC2652P. The module was about 1 from the coordinator. After a first try it was interviewed in Z2M and appears in the device list with all 20 buttons, link quatlity and battery information.
I'm able to setup each button (switch type and switch action). These 'entities' also appear in Home Assistant but I don't know how to be able to see the state change of a button when it is pressed. Used the MQTT dump feature in developer tools but the output file remains empty when I pressed the button...

leoujz, 2022-03-08:
I use external usb cable as a power supply. I did not use Z2M in HomeAssistant, I use a standalone Zigbee2MQTT version running on an arm64 board. I'll try that later

phoenix1589, 2022-03-19:
I've attempted to make a handful of these, with chips from 2 different orders. In all cases, the keypad is consistently able to pair with zigbee2mqtt (Conbee_2 coordinator).

Some of the buttons (1, 10-16, 20) work and appear in the zigbee2mqtt logs. The other buttons do not appear in the logs, however the LED does flash when I press them.

Changing the actions in exposes always works; however consistently if the keypad is not close to the coordinator I need to press a button on the keypad a moment after making the change in zibgee2mqtt. This consistently works, although seems a little strange to be needed.

If I bind one of the 'non-working' buttons to a different device; then the button does work to control the device - I still can't get it to log in zigbee2mqtt (which is what I want, as I want it all done via home assistant).

>(5) in devices binding/reporting setting page, sometimes set it successfully, and the button starts to work, report single/double/triple, and etc.

What specific setting do you set in binding or reporting to get it to start to log in zigbee2mqtt?

Do you see different behaviour with different buttons like O do?

leoujz, 2022-03-27:
yes, I do see  different behavior with different buttons, and for the same button, it has different behavior in many tries of paring process. I think sometimes the configuration might not success for all 20 buttons, some buttons failed but did not fail all times(in my dozens of tries, it only successes 1-2 times).
I debug the source code, I think all the code is running as expected, I think there must be something wrong with ZStack code running on CC2530. I heard from other people that ZStack 3.0 is hard to running on CC2530 because of limited hardware resource. But I'm not professional on Zigbee, just a guess.

phoenix1589, 2022-03-27:
I guess it's possible. I've read through the code and can't see anything that would treat the buttons differently but for me I get consistent behaviour every time across all 4 units I've made.

There is the original firmware on the modkam.ru site which might be worth a try.

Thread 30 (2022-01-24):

How to flash E18-MS1-PCB?

johanvh83, 2022-01-24:
Hi, I want to reproduce your Zigbee keypad. Ordered E18-MS1-PCB.
I was able in the past to flash a CC2652RB USB stick with a .hex file.
As far as I understood I should flash the E18-MS1-PCB with the DIYRuZ_FreePad.hex file.
How can I connect the E18-MS1-PCB to my PC?
Do I need a USB to Serial TTL convertor like the CH340? https://nl.aliexpress.com/item/32761423124.html?gatewayAdapt=glo2nld&spm=a2g0o.9042311.0.0.27424c4dkahs6F
If yes, could you please clarify where to connect the RX and TX line to the E18-MS1-PCB.
If I'm complety wrong, please give me a hint how to put the .hex file in the E18-MS1-PCB.
Thanks in advance!

phoenix1589, 2022-02-27:
I followed https://www.zigbee2mqtt.io/guide/adapters/flashing/alternative_flashing_methods.html, using the 5 'debugger' pads on the board.

 P2.1 as DD and P2.2 ad DC. Rest of pins as labelled in that page

johanvh83, 2022-03-03:
Thanks, used also some other websites and ordered and used the CC Debugger.

Closed 2022-03-03.

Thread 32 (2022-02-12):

Only some buttons work (LED always flashes)

phoenix1589, 2022-02-12:
I've built and flashed a keypad with 20 buttons (DIYRuZ_FreePad.hex). This has paired fine with zigbee2mqtt, and pressing every button I always get a LED flash however only some of the buttons actually have an action received in zigbee2mqtt - specifically buttons 1, and 10-16.

As the LED flashes, I don't see how it could be bad soldering.

Anyone seen this before / have any ideas why only some work?

p1ne, 2023-10-30:
@phoenix1589 any successful fixes of that? I've caught my non-actionnable buttons yesterday - 15-16, 19 in my case

phoenix1589, 2023-10-30:
I've not looked at this in ages, and I never got it working properly.

I have a vague recollection of rebinding some buttons to OnOff and then making a slight change to zigbee2mqtt to cope with just on and off - but I didn't work out how to do that change properly / nearly

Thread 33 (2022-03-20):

Error afer endpoint setting change

johanvh83, 2022-03-20:
When I change one of the endpoint settings, either switch_type or switch_action I get an error:
`Publish 'get' 'switch_type' to 'alarm' failed: 'Error: Read 0x00124b00254b2b06/2 genOnOffSwitchCfg(["switchType","switchActions"], {"sendWhen":"immediate","timeout":10000,"disableResponse":false,"disableRecovery":false,"disableDefaultResponse":true,"direction":0,"srcEndpoint":null,"reservedBits":0,"manufacturerCode":null,"transactionSequenceNumber":null,"writeUndiv":false}) failed (Timeout - 61893 - 2 - 55 - 7 - 1 after 10000ms)'`
When I refresh the specific settings, the change is not made and remains the existing setting

phoenix1589, 2022-03-22:
Try pushing any button on the remote after you set the endpoint setting (doesn't need to be the same button you're trying to set).

This consistently works for me.

If the remote is close to the controller, I don't need to do this and the setting 'just works'

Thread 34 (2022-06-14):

Binding unsuccesful zigbee2mqtt deconz 2

RayJayVaughn, 2022-06-14:
Hi there

Unfortunately I am not able binding the freepad with zigbee2mqtt and deconz 2. Nor am I able binding it with e.g. iobroker.zigbee and deconz 2.

When I try the binding attempt, waiting for the led flashing fast, releasing the button, I always get 3 times led flashing to show a binding error.

It would be a pity causexthe hardware is brilliant. Any idea?

Thanks in advance.

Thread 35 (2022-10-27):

Not all buttons working in ZHA

delta010, 2022-10-27:
I am using an 8-button free pad, first 4 buttons are working those will fire an event without any problem the buttons 5 to 8 not firing any event data

Home assistant device diagnostics
```
{
  "home_assistant": {
    "installation_type": "Home Assistant Container",
    "version": "2022.10.5",
    "dev": false,
    "hassio": false,
    "virtualenv": false,
    "python_version": "3.10.5",
    "docker": true,
    "arch": "x86_64",
    "timezone": "UTC",
    "os_name": "Linux",
    "os_version": "5.18.0-kali7-amd64",
    "run_as_root": true
  },
  "custom_components": {},
  "integration_manifest": {
    "domain": "zha",
    "name": "Zigbee Home Automation",
    "config_flow": true,
    "documentation": "https://www.home-assistant.io/integrations/zha",
    "requirements": [
      "bellows==0.34.2",
      "pyserial==3.5",
      "pyserial-asyncio==0.6",
      "zha-quirks==0.0.83",
      "zigpy-deconz==0.19.0",
      "zigpy==0.51.3",
      "zigpy-xbee==0.16.2",
      "zigpy-zigate==0.10.2",
      "zigpy-znp==0.9.1"
    ],
    "usb": [
      {
        "vid": "10C4",
        "pid": "EA60",
        "description": "*2652*",
        "known_devices": [
          "slae.sh cc2652rb stick"
        ]
      },
      {
        "vid": "1A86",
        "pid": "55D4",
        "description": "*sonoff*plus*",
        "known_devices": [
          "sonoff zigbee dongle plus v2"
        ]
      },
      {
        "vid": "10C4",
        "pid": "EA60",
        "description": "*sonoff*plus*",
        "known_devices": [
          "sonoff zigbee dongle plus"
        ]
      },
      {
        "vid": "10C4",
        "pid": "EA60",
        "description": "*tubeszb*",
        "known_devices": [
          "TubesZB Coordinator"
        ]
      },
      {
        "vid": "1A86",
        "pid": "7523",
        "description": "*tubeszb*",
        "known_devices": [
          "TubesZB Coordinator"
        ]
      },
      {
        "vid": "1A86",
        "pid": "7523",
        "description": "*zigstar*",
        "known_devices": [
          "ZigStar Coordinators"
        ]
      },
      {
        "vid": "1CF1",
        "pid": "0030",
        "description": "*conbee*",
        "known_devices": [
          "Conbee II"
        ]
      },
      {
        "vid": "10C4",
        "pid": "8A2A",
        "description": "*zigbee*",
        "known_devices": [
          "Nortek HUSBZB-1"
        ]
      },
      {
        "vid": "0403",
        "pid": "6015",
        "description": "*zigate*",
        "known_devices": [
          "ZiGate+"
        ]
      },
      {
        "vid": "10C4",
        "pid": "EA60",
        "description": "*zigate*",
        "known_devices": [
          "ZiGate"
        ]
      },
      {
        "vid": "10C4",
        "pid": "8B34",
        "description": "*bv 2010/10*",
        "known_devices": [
          "Bitron Video AV2010/10"
        ]
      }
    ],
    "codeowners": [
      "@dmulcahey",
      "@adminiuga",
      "@puddly"
    ],
    "zeroconf": [
      {
        "type": "_esphomelib._tcp.local.",
        "name": "tube*"
      },
      {
        "type": "_zigate-zigbee-gateway._tcp.local.",
        "name": "*zigate*"
      },
      {
        "type": "_zigstar_gw._tcp.local.",
        "name": "*zigstar*"
      }
    ],
    "dependencies": [
      "file_upload"
    ],
    "after_dependencies": [
      "onboarding",
      "usb",
      "zeroconf"
    ],
    "iot_class": "local_polling",
    "loggers": [
      "aiosqlite",
      "bellows",
      "crccheck",
      "pure_pcapy3",
      "zhaquirks",
      "zigpy",
      "zigpy_deconz",
      "zigpy_xbee",
      "zigpy_zigate",
      "zigpy_znp"
    ],
    "is_built_in": true
  },
  "data": {
    "ieee": "**REDACTED**",
    "nwk": 49976,
    "manufacturer": "modkam.ru",
    "model": "DIYRuZ_FreePad",
    "name": "modkam.ru DIYRuZ_FreePad",
    "quirk_applied": false,
    "quirk_class": "zigpy.device.Device",
    "manufacturer_code": 0,
    "power_source": "Battery or Unknown",
    "lqi": 65,
    "rssi": null,
    "last_seen": "2022-10-27T10:11:30",
    "available": true,
    "device_type": "EndDevice",
    "signature": {
      "node_descriptor": "NodeDescriptor(logical_type=<LogicalType.EndDevice: 2>, complex_descriptor_available=0, user_descriptor_available=0, reserved=0, aps_flags=0, frequency_band=<FrequencyBand.Freq2400MHz: 8>, mac_capability_flags=<MACCapabilityFlags.AllocateAddress: 128>, manufacturer_code=0, maximum_buffer_size=80, maximum_incoming_transfer_size=160, server_mask=0, maximum_outgoing_transfer_size=160, descriptor_capability_field=<DescriptorCapability.NONE: 0>, *allocate_address=True, *is_alternate_pan_coordinator=False, *is_coordinator=False, *is_end_device=True, *is_full_function_device=False, *is_mains_powered=False, *is_receiver_on_when_idle=False, *is_router=False, *is_security_capable=False)",
      "endpoints": {
        "1": {
          "profile_id": 260,
          "device_type": "0x0006",
          "in_clusters": [
            "0x0000"
          ],
          "out_clusters": [
            "0x0006",
            "0x0008",
            "0x0012",
            "0x0300"
          ]
        },
        "2": {
          "profile_id": 260,
          "device_type": "0x0006",
          "in_clusters": [],
          "out_clusters": [
            "0x0006",
            "0x0012"
          ]
        },
        "3": {
          "profile_id": 260,
          "device_type": "0x0006",
          "in_clusters": [],
          "out_clusters": [
            "0x0006",
            "0x0012"
          ]
        },
        "4": {
          "profile_id": 260,
          "device_type": "0x0006",
          "in_clusters": [],
          "out_clusters": [
            "0x0006",
            "0x0012"
          ]
        },
        "5": {
          "profile_id": 260,
          "device_type": "0x0006",
          "in_clusters": [],
          "out_clusters": [
            "0x0006",
            "0x0008",
            "0x0012",
            "0x0300"
          ]
        },
        "6": {
          "profile_id": 260,
          "device_type": "0x0006",
          "in_clusters": [],
          "out_clusters": [
            "0x0006",
            "0x0012"
          ]
        },
        "7": {
          "profile_id": 260,
          "device_type": "0x0006",
          "in_clusters": [],
          "out_clusters": [
            "0x0006",
            "0x0012"
          ]
        },
        "8": {
          "profile_id": 260,
          "device_type": "0x0006",
          "in_clusters": [],
          "out_clusters": [
            "0x0006",
            "0x0012"
          ]
        },
        "9": {
          "profile_id": 260,
          "device_type": "0x0006",
          "in_clusters": [],
          "out_clusters": [
            "0x0006",
            "0x0008",
            "0x0012",
            "0x0300"
          ]
        },
        "10": {
          "profile_id": 260,
          "device_type": "0x0006",
          "in_clusters": [],
          "out_clusters": [
            "0x0006",
            "0x0012"
          ]
        },
        "11": {
          "profile_id": 260,
          "device_type": "0x0006",
          "in_clusters": [],
          "out_clusters": [
            "0x0006",
            "0x0012"
          ]
        },
        "12": {
          "profile_id": 260,
          "device_type": "0x0006",
          "in_clusters": [],
          "out_clusters": [
            "0x0006",
            "0x0012"
          ]
        },
        "13": {
          "profile_id": 260,
          "device_type": "0x0006",
          "in_clusters": [],
          "out_clusters": [
            "0x0006",
            "0x0008",
            "0x0012",
            "0x0300"
          ]
        },
        "14": {
          "profile_id": 260,
          "device_type": "0x0006",
          "in_clusters": [],
          "out_clusters": [
            "0x0006",
            "0x0012"
          ]
        },
        "15": {
          "profile_id": 260,
          "device_type": "0x0006",
          "in_clusters": [],
          "out_clusters": [
            "0x0006",
            "0x0012"
          ]
        },
        "16": {
          "profile_id": 260,
          "device_type": "0x0006",
          "in_clusters": [],
          "out_clusters": [
            "0x0006",
            "0x0012"
          ]
        },
        "17": {
          "profile_id": 260,
          "device_type": "0x0006",
          "in_clusters": [],
          "out_clusters": [
            "0x0006",
            "0x0008",
            "0x0012",
            "0x0300"
          ]
        },
        "18": {
          "profile_id": 260,
          "device_type": "0x0006",
          "in_clusters": [],
          "out_clusters": [
            "0x0006",
            "0x0012"
          ]
        },
        "19": {
          "profile_id": 260,
          "device_type": "0x0006",
          "in_clusters": [],
          "out_clusters": [
            "0x0006",
            "0x0012"
          ]
        },
        "20": {
          "profile_id": 260,
          "device_type": "0x0006",
          "in_clusters": [],
          "out_clusters": [
            "0x0006",
            "0x0012"
          ]
        }
      }
    },
    "active_coordinator": false,
    "entities": [],
    "neighbors": [],
    "endpoint_names": [
      {
        "name": "REMOTE_CONTROL"
      },
      {
        "name": "REMOTE_CONTROL"
      },
      {
        "name": "REMOTE_CONTROL"
      },
      {
        "name": "REMOTE_CONTROL"
      },
      {
        "name": "REMOTE_CONTROL"
      },
      {
        "name": "REMOTE_CONTROL"
      },
      {
        "name": "REMOTE_CONTROL"
      },
      {
        "name": "REMOTE_CONTROL"
      },
      {
        "name": "REMOTE_CONTROL"
      },
      {
        "name": "REMOTE_CONTROL"
      },
      {
        "name": "REMOTE_CONTROL"
      },
      {
        "name": "REMOTE_CONTROL"
      },
      {
        "name": "REMOTE_CONTROL"
      },
      {
        "name": "REMOTE_CONTROL"
      },
      {
        "name": "REMOTE_CONTROL"
      },
      {
        "name": "REMOTE_CONTROL"
      },
      {
        "name": "REMOTE_CONTROL"
      },
      {
        "name": "REMOTE_CONTROL"
      },
      {
        "name": "REMOTE_CONTROL"
      },
      {
        "name": "REMOTE_CONTROL"
      }
    ],
    "user_given_name": null,
    "device_reg_id": "049629de53bc6753e6e007adbc3e7238",
    "area_id": null,
    "cluster_details": {
      "20": {
        "device_type": {
          "name": "REMOTE_CONTROL",
          "id": 6
        },
        "profile_id": 260,
        "in_clusters": {},
        "out_clusters": {
          "0x0006": {
            "endpoint_attribute": "on_off",
            "attributes": {},
            "unsupported_attributes": {}
          },
          "0x0012": {
            "endpoint_attribute": "multistate_input",
            "attributes": {},
            "unsupported_attributes": {}
          }
        }
      },
      "19": {
        "device_type": {
          "name": "REMOTE_CONTROL",
          "id": 6
        },
        "profile_id": 260,
        "in_clusters": {},
        "out_clusters": {
          "0x0006": {
            "endpoint_attribute": "on_off",
            "attributes": {},
            "unsupported_attributes": {}
          },
          "0x0012": {
            "endpoint_attribute": "multistate_input",
            "attributes": {},
            "unsupported_attributes": {}
          }
        }
      },
      "18": {
        "device_type": {
          "name": "REMOTE_CONTROL",
          "id": 6
        },
        "profile_id": 260,
        "in_clusters": {},
        "out_clusters": {
          "0x0006": {
            "endpoint_attribute": "on_off",
            "attributes": {},
            "unsupported_attributes": {}
          },
          "0x0012": {
            "endpoint_attribute": "multistate_input",
            "attributes": {},
            "unsupported_attributes": {}
          }
        }
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

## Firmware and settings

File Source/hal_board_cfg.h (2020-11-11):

#ifndef HAL_BOARD_CFG_H
#define HAL_BOARD_CFG_H


/* ------------------------------------------------------------------------------------------------
 *                                           Includes
 * ------------------------------------------------------------------------------------------------
 */

#include "hal_mcu.h"
#include "hal_defs.h"
#include "hal_types.h"



/* ------------------------------------------------------------------------------------------------
 *                                          Clock Speed
 * ------------------------------------------------------------------------------------------------
 */

#define HAL_CPU_CLOCK_MHZ     32

/* 32 kHz clock source select in CLKCONCMD */
#if !defined (OSC32K_CRYSTAL_INSTALLED) || (defined (OSC32K_CRYSTAL_INSTALLED) && (OSC32K_CRYSTAL_INSTALLED == TRUE))
#define OSC_32KHZ  0x00 /* external 32 KHz xosc */
#else
#define OSC_32KHZ  0x80 /* internal 32 KHz rcosc */
#endif

#define HAL_CLOCK_STABLE() 

/* ------------------------------------------------------------------------------------------------
 *                                         Key Release detect support
 * ------------------------------------------------------------------------------------------------
 */
#define HAL_KEY_CODE_NOKEY 0xff


/* ------------------------------------------------------------------------------------------------
 *                                       LED Configuration
 * ------------------------------------------------------------------------------------------------
 */

// TODO: review all HAL_BOARD_CC2530EB_REV17 and replace with HAL_BOARD_CC2530RC
//       if applicable.
#define HAL_NUM_LEDS            0

#define HAL_LED_BLINK_DELAY()   st( { volatile uint32 i; for (i=0; i<0x5800; i++) { }; } )
#define ACTIVE_LOW        !
#define ACTIVE_HIGH       !!    /* double negation forces result to be '1' */

/* ------------------------------------------------------------------------------------------------
 *                         OSAL NV implemented by internal flash pages.
 * ------------------------------------------------------------------------------------------------
 */

// Flash is partitioned into 8 banks of 32 KB or 16 pages.
#define HAL_FLASH_PAGE_PER_BANK    16
// Flash is constructed of 128 pages of 2 KB.
#define HAL_FLASH_PAGE_SIZE        2048
#define HAL_FLASH_WORD_SIZE        4

// CODE banks get mapped into the XDATA range 8000-FFFF.
#define HAL_FLASH_PAGE_MAP         0x8000

// The last 16 bytes of the last available page are reserved for flash lock bits.
// NV page definitions must coincide with segment declaration in project *.xcl file.
#if defined NON_BANKED
#define HAL_FLASH_LOCK_BITS        16
#define HAL_NV_PAGE_END            30
#define HAL_NV_PAGE_CNT            2
#else
#define HAL_FLASH_LOCK_BITS        16
#define HAL_NV_PAGE_END            126
#define HAL_NV_PAGE_CNT            6
#endif

// Re-defining Z_EXTADDR_LEN here so as not to include a Z-Stack .h file.
#define HAL_FLASH_IEEE_SIZE        8
#define HAL_FLASH_IEEE_PAGE       (HAL_NV_PAGE_END+1)
#define HAL_FLASH_IEEE_OSET       (HAL_FLASH_PAGE_SIZE - HAL_FLASH_LOCK_BITS - HAL_FLASH_IEEE_SIZE)
#define HAL_INFOP_IEEE_OSET        0xC

#define HAL_FLASH_DEV_PRIVATE_KEY_OSET     0x7D2
#define HAL_FLASH_CA_PUBLIC_KEY_OSET       0x7BC
#define HAL_FLASH_IMPLICIT_CERT_OSET       0x78C

#define HAL_NV_PAGE_BEG           (HAL_NV_PAGE_END-HAL_NV_PAGE_CNT+1)
// Used by DMA macros to shift 1 to create a mask for DMA registers.
#define HAL_NV_DMA_CH              0
#define HAL_DMA_CH_RX              3
#define HAL_DMA_CH_TX              4

#define HAL_NV_DMA_GET_DESC()      HAL_DMA_GET_DESC0()
#define HAL_NV_DMA_SET_ADDR(a)     HAL_DMA_SET_ADDR_DESC0((a))

/* ------------------------------------------------------------------------------------------------
 *  Serial Boot Loader: reserving the first 4 pages of flash and other memory in cc2530-sb.xcl.
 * ------------------------------------------------------------------------------------------------
 */

#define HAL_SB_IMG_ADDR       0x2000
#define HAL_SB_CRC_ADDR       0x2090
// Size of internal flash less 4 pages for boot loader, 6 pages for NV, & 1 page for lock bits.
#define HAL_SB_IMG_SIZE      (0x40000 - 0x2000 - 0x3000 - 0x0800)

/* ------------------------------------------------------------------------------------------------
 *                                            Macros
 * ------------------------------------------------------------------------------------------------
 */

/* ----------- RF-frontend Connection Initialization ---------- */
#if defined HAL_PA_LNA || defined HAL_PA_LNA_CC2590
extern void MAC_RfFrontendSetup(void);
#define HAL_BOARD_RF_FRONTEND_SETUP() MAC_RfFrontendSetup()
#else
#define HAL_BOARD_RF_FRONTEND_SETUP()
#endif
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

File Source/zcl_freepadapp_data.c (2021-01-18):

#include "AF.h"
#include "OSAL.h"
#include "ZComDef.h"
#include "ZDConfig.h"

#include "zcl.h"
#include "zcl_general.h"
#include "zcl_ha.h"

#include "zcl_freepadapp.h"

#include "battery.h"
#include "version.h"
/*********************************************************************
 * CONSTANTS
 */
#define FREEPADAPP_DEVICE_VERSION 2

#define FREEPADAPP_FLAGS 0

#define FREEPADAPP_HWVERSION 1
#define FREEPADAPP_ZCLVERSION 1

/*********************************************************************
 * TYPEDEFS
 */

/*********************************************************************
 * MACROS
 */

/*********************************************************************
 * GLOBAL VARIABLES
 */

// Global attributes
const uint16 zclFreePadApp_clusterRevision_all = 0x0001;

// Basic Cluster
const uint8 zclFreePadApp_HWRevision = FREEPADAPP_HWVERSION;
const uint8 zclFreePadApp_ZCLVersion = FREEPADAPP_ZCLVERSION;

#if BDB_REPORTING
const uint8 zclFreePadApp_ApplicationVersion = 2;
#else
const uint8 zclFreePadApp_ApplicationVersion = 3;
#endif
const uint8 zclFreePadApp_StackVersion = 4;

//{lenght, 'd', 'a', 't', 'a'}
const uint8 zclFreePadApp_ManufacturerName[] = {9, 'm', 'o', 'd', 'k', 'a', 'm', '.', 'r', 'u'};
#if defined(HAL_BOARD_LETV)
const uint8 zclFreePadApp_ModelId[] = {14, 'F', 'r', 'e', 'e', 'P', 'a', 'd', '_', 'L', 'e', 'T', 'V', '_', '8'};
#else
const uint8 zclFreePadApp_ModelId[] = {14, 'D', 'I', 'Y', 'R', 'u', 'Z', '_', 'F', 'r', 'e', 'e', 'P', 'a', 'd'};
#endif

const uint8 zclFreePadApp_PowerSource = POWER_SOURCE_BATTERY;

uint8 zclFreePadApp_SwitchActions[FREEPAD_BUTTONS_COUNT];
uint8 zclFreePadApp_SwitchTypes[FREEPAD_BUTTONS_COUNT];

/*********************************************************************
 * ATTRIBUTE DEFINITIONS - Uses REAL cluster IDs
 */
#define R ACCESS_CONTROL_READ
#define RR R | ACCESS_REPORTABLE
#define RW (R | ACCESS_CONTROL_WRITE | ACCESS_CONTROL_AUTH_WRITE)
#define BASIC ZCL_CLUSTER_ID_GEN_BASIC
#define POWER_CFG ZCL_CLUSTER_ID_GEN_POWER_CFG
#define SWITCH_CONFIG ZCL_CLUSTER_ID_GEN_ON_OFF_SWITCH_CONFIG
#define ON_OFF ZCL_CLUSTER_ID_GEN_ON_OFF
#define MS_INP_BASIC ZCL_CLUSTER_ID_GEN_MULTISTATE_INPUT_BASIC
#define ZCL_UINT8 ZCL_DATATYPE_UINT8


CONST zclAttrRec_t zclFreePadApp_AttrsFirstEP[] = {
    {BASIC, {ATTRID_BASIC_ZCL_VERSION, ZCL_UINT8, R, (void *)&zclFreePadApp_ZCLVersion}},
    {BASIC, {ATTRID_BASIC_APPL_VERSION, ZCL_UINT8, R, (void *)&zclFreePadApp_ApplicationVersion}},
    {BASIC, {ATTRID_BASIC_STACK_VERSION, ZCL_UINT8, R, (void *)&zclFreePadApp_StackVersion}},
    {BASIC, {ATTRID_BASIC_HW_VERSION, ZCL_UINT8, R, (void *)&zclFreePadApp_HWRevision}},

    {BASIC, {ATTRID_BASIC_MANUFACTURER_NAME, ZCL_DATATYPE_CHAR_STR, R, (void *)zclFreePadApp_ManufacturerName}},
    {BASIC, {ATTRID_BASIC_MODEL_ID, ZCL_DATATYPE_CHAR_STR, R, (void *)zclFreePadApp_ModelId}},
    {BASIC, {ATTRID_BASIC_DATE_CODE, ZCL_DATATYPE_CHAR_STR, R, (void *)zclFreePadApp_DateCode}},
    {BASIC, {ATTRID_BASIC_POWER_SOURCE, ZCL_DATATYPE_ENUM8, R, (void *)&zclFreePadApp_PowerSource}},
    {BASIC, {ATTRID_BASIC_SW_BUILD_ID, ZCL_UINT8, R, (void *)&zclFreePadApp_ApplicationVersion}},
    {BASIC, {ATTRID_CLUSTER_REVISION, ZCL_DATATYPE_UINT16, R, (void *)&zclFreePadApp_clusterRevision_all}},
    {POWER_CFG, {ATTRID_POWER_CFG_BATTERY_VOLTAGE, ZCL_UINT8, RR, (void *)&zclBattery_Voltage}},
    {POWER_CFG, {ATTRID_POWER_CFG_BATTERY_PERCENTAGE_REMAINING, ZCL_UINT8, RR, (void *)&zclBattery_PercentageRemainig}},

    {SWITCH_CONFIG, {ATTRID_ON_OFF_SWITCH_TYPE, ZCL_DATATYPE_ENUM8, RW, (void *)&zclFreePadApp_SwitchTypes[0]}},
    {SWITCH_CONFIG, {ATTRID_ON_OFF_SWITCH_ACTIONS, ZCL_DATATYPE_ENUM8, RW, (void *)&zclFreePadApp_SwitchActions[0]}}};

CONST zclAttrRec_t zclFreePadApp_Attrs[][FREEPAD_ATTRS_COUNT] = {

    {{SWITCH_CONFIG, {ATTRID_ON_OFF_SWITCH_TYPE, ZCL_DATATYPE_ENUM8, RW, (void *)&zclFreePadApp_SwitchTypes[1]}},
     {SWITCH_CONFIG, {ATTRID_ON_OFF_SWITCH_ACTIONS, ZCL_DATATYPE_ENUM8, RW, (void *)&zclFreePadApp_SwitchActions[1]}}},
    
    {{SWITCH_CONFIG, {ATTRID_ON_OFF_SWITCH_TYPE, ZCL_DATATYPE_ENUM8, RW, (void *)&zclFreePadApp_SwitchTypes[2]}},
     {SWITCH_CONFIG, {ATTRID_ON_OFF_SWITCH_ACTIONS, ZCL_DATATYPE_ENUM8, RW, (void *)&zclFreePadApp_SwitchActions[2]}}},
    
    {{SWITCH_CONFIG, {ATTRID_ON_OFF_SWITCH_TYPE, ZCL_DATATYPE_ENUM8, RW, (void *)&zclFreePadApp_SwitchTypes[3]}},
     {SWITCH_CONFIG, {ATTRID_ON_OFF_SWITCH_ACTIONS, ZCL_DATATYPE_ENUM8, RW, (void *)&zclFreePadApp_SwitchActions[3]}}},

    {{SWITCH_CONFIG, {ATTRID_ON_OFF_SWITCH_TYPE, ZCL_DATATYPE_ENUM8, RW, (void *)&zclFreePadApp_SwitchTypes[4]}},
     {SWITCH_CONFIG, {ATTRID_ON_OFF_SWITCH_ACTIONS, ZCL_DATATYPE_ENUM8, RW, (void *)&zclFreePadApp_SwitchActions[4]}}},

    {{SWITCH_CONFIG, {ATTRID_ON_OFF_SWITCH_TYPE, ZCL_DATATYPE_ENUM8, RW, (void *)&zclFreePadApp_SwitchTypes[5]}},
     {SWITCH_CONFIG, {ATTRID_ON_OFF_SWITCH_ACTIONS, ZCL_DATATYPE_ENUM8, RW, (void *)&zclFreePadApp_SwitchActions[5]}}},

    {{SWITCH_CONFIG, {ATTRID_ON_OFF_SWITCH_TYPE, ZCL_DATATYPE_ENUM8, RW, (void *)&zclFreePadApp_SwitchTypes[6]}},
     {SWITCH_CONFIG, {ATTRID_ON_OFF_SWITCH_ACTIONS, ZCL_DATATYPE_ENUM8, RW, (void *)&zclFreePadApp_SwitchActions[6]}}},

    {{SWITCH_CONFIG, {ATTRID_ON_OFF_SWITCH_TYPE, ZCL_DATATYPE_ENUM8, RW, (void *)&zclFreePadApp_SwitchTypes[7]}},
     {SWITCH_CONFIG, {ATTRID_ON_OFF_SWITCH_ACTIONS, ZCL_DATATYPE_ENUM8, RW, (void *)&zclFreePadApp_SwitchActions[7]}}},

    {{SWITCH_CONFIG, {ATTRID_ON_OFF_SWITCH_TYPE, ZCL_DATATYPE_ENUM8, RW, (void *)&zclFreePadApp_SwitchTypes[8]}},
     {SWITCH_CONFIG, {ATTRID_ON_OFF_SWITCH_ACTIONS, ZCL_DATATYPE_ENUM8, RW, (void *)&zclFreePadApp_SwitchActions[8]}}},

    {{SWITCH_CONFIG, {ATTRID_ON_OFF_SWITCH_TYPE, ZCL_DATATYPE_ENUM8, RW, (void *)&zclFreePadApp_SwitchTypes[9]}},
     {SWITCH_CONFIG, {ATTRID_ON_OFF_SWITCH_ACTIONS, ZCL_DATATYPE_ENUM8, RW, (void *)&zclFreePadApp_SwitchActions[9]}}},

    {{SWITCH_CONFIG, {ATTRID_ON_OFF_SWITCH_TYPE, ZCL_DATATYPE_ENUM8, RW, (void *)&zclFreePadApp_SwitchTypes[10]}},
     {SWITCH_CONFIG, {ATTRID_ON_OFF_SWITCH_ACTIONS, ZCL_DATATYPE_ENUM8, RW, (void *)&zclFreePadApp_SwitchActions[10]}}},

    {{SWITCH_CONFIG, {ATTRID_ON_OFF_SWITCH_TYPE, ZCL_DATATYPE_ENUM8, RW, (void *)&zclFreePadApp_SwitchTypes[11]}},
     {SWITCH_CONFIG, {ATTRID_ON_OFF_SWITCH_ACTIONS, ZCL_DATATYPE_ENUM8, RW, (void *)&zclFreePadApp_SwitchActions[11]}}},

    {{SWITCH_CONFIG, {ATTRID_ON_OFF_SWITCH_TYPE, ZCL_DATATYPE_ENUM8, RW, (void *)&zclFreePadApp_SwitchTypes[12]}},
     {SWITCH_CONFIG, {ATTRID_ON_OFF_SWITCH_ACTIONS, ZCL_DATATYPE_ENUM8, RW, (void *)&zclFreePadApp_SwitchActions[12]}}},

    {{SWITCH_CONFIG, {ATTRID_ON_OFF_SWITCH_TYPE, ZCL_DATATYPE_ENUM8, RW, (void *)&zclFreePadApp_SwitchTypes[13]}},
     {SWITCH_CONFIG, {ATTRID_ON_OFF_SWITCH_ACTIONS, ZCL_DATATYPE_ENUM8, RW, (void *)&zclFreePadApp_SwitchActions[13]}}},
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

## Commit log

2020-05-26 Slighgliy refactor battery
2020-05-26 Fix battery conversions
2020-05-26 Debug for non uart boards
2020-05-28 Increase default bindings count by 4
    [preinclude.h]
2020-05-28 Send battery report after binding
    [zcl_freepadapp.c]
2020-05-30 Fix touchlink (memory issue)
    [preinclude.h, zcl_freepadapp.h]
2020-06-02 Battery calibration
2020-06-23 Disable data pooling
    [f8wConfig.cfg]
2020-06-23 use z2m BatteryRemainingPercentage formula thanks to @koptserg
2020-08-02 introduce zstack-lib
    [f8wConfig.cfg]
2020-08-05 Send commands to binded devices without delays
2020-08-06 Refactor battery reporting
2020-08-08 Refactor TL
    [f8wConfig.cfg]
2020-11-10 Added: init of LED2 Changed: LED2 blinking on key push Configuration for original Freepad using one pin for both LED1 and LED2.
2020-11-11 fix power saving on LeTV fix green led on LeTV thanks to Сергей Коптяков from https://t.me/zigdev
    [hal_board_cfg.h, preinclude.h]
2021-01-28 freepad v1 description
    [case_v1.STL, top_glass_v1.DXF]
2021-01-28 freepad v2 description
    [case_v2_8key_bottom.STL, case_v2_8key_top.STL]
2021-01-28 added dxf and some fixes
    [LeTV_pogopin.dxf]
